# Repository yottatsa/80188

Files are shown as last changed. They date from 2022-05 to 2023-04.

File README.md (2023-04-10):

# 80188 single board modular computer

* testing and firmware development: r1
* hardware development: r2
  - [CPU card](https://github.com/yottatsa/80188/blob/main/cpu_card/cpu_card/cpu_card.pdf)
  - [ISP interface](https://github.com/yottatsa/80188/blob/main/cpu_card/isp_interface/isp_interface.pdf)

To emulate

    make run

To program and connect

    make all
    minipro -p SST39SF020A@PLCC32 --write fw/fw.bin
    minipro -p ... --write gal/....pld
    ...
    picocom -q --baud 9600 --imap lfcrlf --omap crlf [serial device]

## Configuration

* 8MHz 8086-compatible CPU
* 128KB low SRAM
* 256KB EEPROM (27C020) or Flash (SST39SF020) with in-system programming and software programming capabilities
* PC/104-compatible with 8-bit ISA bus
  - 80188 Timer A is routed to OSC
* Dual channel 16550-compatible UART
  - FTDI USB-Serial/6-pin connector on port A
  - 5V 9pin connector on port B
* AT-compatible RTC

## Notes

### r1

* minor: SYSBUS socket is too close to the CPU socket and can'tbe used with the wide connector
* minor: 16V8 /OE and GND pin names were swapped
* minor: UART1 labels are wrong
* major: 74x573 OE should be /OE
* major: 16V8 /RESET can't be used as input
* major: PLCC sockets are unreliable
* unknown: 22V10 Verification failed at address 0x16C5: File=0x01, Device=0x00
* feature: added in-system programming
* major: 39x flash doesn't work as /PGM is floating

### r0
* major: PCB socket is unreliable

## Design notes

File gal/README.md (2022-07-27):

## Board verification

- GAL is compilable and flash-able

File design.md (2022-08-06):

## References
* [Tandy 2000 BIOS](https://www.retrotronics.org/svn/t2kbios/)
* AMD 80C186/80C188 Preliminary
* Intel 80C186EA/80C188EA Microprocessor User's Manual

## Similar
* http://www.testech-elect.com/tern/acore.htm
* https://www.embeddedts.com/products/TS-2100
* https://www.jamieiles.com/80186/
* https://www.retrobrewcomputers.org/doku.php?id=boards:sbc:sbc-188:start
* https://www.kswichit.com/C188/c188sbc.htm

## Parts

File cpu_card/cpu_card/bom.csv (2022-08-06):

Item | Qty | Reference(s) | Value | LibPart | Footprint | Datasheet | Allied_Number | Description | Height | Manufacturer_Name | Manufacturer_Part_Number | Mouser Part Number | Mouser Price/Stock | RS Part Number | RS Price/Stock
1 | 1 | BT301 | RTC Battery | Device:Battery_Cell | Battery:BatteryHolder_Keystone_106_1x20mm | https://www.mouser.co.uk/datasheet/2/215/06-745914.pdf |  |  |  |  | 106 | 534-106
2 | 1 | C4 | PPWR | Device:C_Polarized_Small | Capacitor_Tantalum_SMD:CP_EIA-7343-31_Kemet-D | ~ |  |  |  |  |  | 667-EEF-CS1D100R
3 | 12 | C5, C6, C9, C10, C201, C202, C203, C204, C301, C302, C303, C304 | 100n/0.1u PWR | Device:C_Small | Capacitor_SMD:C_1206_3216Metric_Pad1.33x1.80mm_HandSolder | ~ |  |  |  |  |  | 80-C1206X104G4HACTU
4 | 2 | C101, C305 | 22p XTAL | Device:C_Small | Capacitor_SMD:C_0805_2012Metric_Pad1.18x1.45mm_HandSolder | ~ |  |  |  |  | C0805C220J1GACTU
5 | 1 | C102 | 20p XTAL | Device:C_Small | Capacitor_SMD:C_0805_2012Metric_Pad1.18x1.45mm_HandSolder | ~ |  |  |  |  | C0805C220J1GACTU
6 | 1 | C306 | 33p XTAL | Device:C_Small | Capacitor_SMD:C_0805_2012Metric_Pad1.18x1.45mm_HandSolder | ~ |  |  |  |  | C0805C220J1GACTU
8 | 1 | J1 | 80188 | MCU_Intel:80188 | 80C188:PLCC-68_SMD-Socket | http://datasheets.chipdb.org/Intel/x86/8018x/datashts/27243002.PDF |  |  |  |  | 8468-11B1-RK-TP | 517-8468-11B1-RK-TP
9 | 1 | J2 | PC/104 ISA | Connector_Generic:Conn_02x32_Odd_Even | Connector_PinSocket_2.54mm:PinSocket_2x32_P2.54mm_Vertical | ~
10 | 1 | J4 | 256K ROM | Memory_EPROM:27C020 | 69802-132LF:69802132LF | https://www.mouser.co.uk/datasheet/2/268/20005023B-709002.pdf |  |  |  |  | SST39SF020A-70-4C-NHE | 804-39SF020A7CNHE
11 | 1 | J201 | 22V10/16V8 | Logic_Programmable:PAL24 | Package_DIP:DIP-24_W7.62mm_Socket_LongPads | ~
12 | 1 | J202 | SYSBUS | Connector_Generic:Conn_02x05_Odd_Even | Connector_PinHeader_1.27mm:PinHeader_2x05_P1.27mm_Vertical | ~
13 | 1 | J302 | UART2 | Connector_Generic:Conn_02x05_Odd_Even | Connector_PinSocket_1.27mm:PinSocket_2x05_P1.27mm_Vertical | ~
14 | 1 | J303 | USB B | Connector:USB_B | A-USB_B_SMT:AUSBBSMT | http://uk.rs-online.com/web/p/products/6741331P | R1074095 |  |  |  | A-USB B/SMT |  |  | 6741331P | http://uk.rs-online.com/web/p/products/6741331P
15 | 1 | R1 | TMR1 > | Device:R_Small | Resistor_SMD:R_1206_3216Metric_Pad1.30x1.75mm_HandSolder | ~ |  | 1206 SMD 20 Kohms |  |  |  | 71-RCC120620K0FKEA
16 | 1 | R2 | ARDY | Device:R_Small | Resistor_SMD:R_1206_3216Metric_Pad1.30x1.75mm_HandSolder | ~ |  | 1206 SMD 20 Kohms |  |  |  | 71-RCC120620K0FKEA
17 | 1 | R3 | SRDY | Device:R_Small | Resistor_SMD:R_1206_3216Metric_Pad1.30x1.75mm_HandSolder | ~ |  | 1206 SMD 20 Kohms |  |  |  | 71-RCC120620K0FKEA
18 | 1 | R4 | TMR0 > | Device:R_Small | Resistor_SMD:R_1206_3216Metric_Pad1.30x1.75mm_HandSolder | ~ |  | 1206 SMD 20 Kohms |  |  |  | 71-RCC120620K0FKEA
19 | 1 | R101 | PullUp | Device:R_Small | Resistor_SMD:R_1206_3216Metric_Pad1.30x1.75mm_HandSolder | ~ |  | 1206 SMD 20 Kohms |  |  |  | 71-RCC120620K0FKEA
20 | 1 | R201 | Limit | Device:R_Small | Resistor_SMD:R_1206_3216Metric_Pad1.30x1.75mm_HandSolder | ~ |  | 1206 SMD 20 Kohms |  |  | SFR18EZPJ000 | 755-SFR18EZPJ000
21 | 1 | R302 | R4k7 | Device:R | Resistor_SMD:R_1206_3216Metric_Pad1.30x1.75mm_HandSolder | ~ |  |  |  |  | CR1206-JW-472ELF | 652-CR1206-JW-472ELF
22 | 1 | R303 | R10k | Device:R | Resistor_SMD:R_1206_3216Metric_Pad1.30x1.75mm_HandSolder | ~ |  |  |  |  | CR1206-JW-103ELF | 652-CR1206JW-103ELF
23 | 1 | R304 | PullDown | Device:R_Small | Resistor_SMD:R_1206_3216Metric_Pad1.30x1.75mm_HandSolder | ~ |  | 1206 SMD 20 Kohms |  |  |  | 71-RCC120620K0FKEA
24 | 1 | S1 | PWR | Connector:Screw_Terminal_01x02 | TerminalBlock:TerminalBlock_bornier-2_P5.08mm | ~
25 | 1 | SW201 | RESET | Switch:SW_Push | Button_Switch_SMD:SW_SPST_EVQP7A | https://www.mouser.co.uk/datasheet/2/315/sw_lt_eng_3529s_side-1289027.pdf |  |  |  |  | EVQ-P7J01P | 667-EVQP7J01P
27 | 1 | U4 | 128K SRAM | Memory_RAM:628128_DIP32_SSOP32 | Package_SO:SSOP-32_11.305x20.495mm_P1.27mm | https://www.issi.com/WW/pdf/62-65C1024AL.pdf |  | 62C1024 128KB SRAM |  | ISSI | IS62C1024AL-35QLI
28 | 2 | U201, U203 | 74LS573 | 74xx:74LS573 | Package_SO:SOIC-20W_7.5x12.8mm_P1.27mm | 74xx/74hc573.pdf |  |  |  |  | 74VHCT573AFT |  |  | 171-3540
29 | 1 | U202 | 74LS245 | 74xx:74LS245 | Package_SO:SOIC-20W_7.5x12.8mm_P1.27mm | https://www.mouser.co.uk/datasheet/2/308/1/MC74HCT245A_D-2315802.pdf |  |  |  | Texas Instruments | MC74HCT245ADWG | 863-MC74HCT245ADWG
30 | 1 | U204 | TLV809EA45DBZR | Power_Supervisor:TCM809 | Package_TO_SOT_SMD:SOT-23 | https://www.ti.com/lit/ds/symlink/tlv809e.pdf
31 | 1 | U301 | SC16C752B | SC16C752BIB48_157:SC16C752BIB48,157 | Package_QFP:TQFP-48_7x7mm_P0.5mm | http://www.nxp.com/docs/en/data-sheet/SC16C752B.pdf |  | UART Interface IC 2CH. UART 64B FIFO | 1.6 | NXP | SC16C752BIB48,157 | 771-SC16C752BIB48 | https://www.mouser.co.uk/ProductDetail/NXP-Semiconductors/SC16C752BIB48157?qs=LOCUfHb8d9sKsb5zIyQ%2FFA%3D%3D
32 | 1 | U302 | FT231XS | Interface_USB:FT231XS | Package_SO:SSOP-20_3.9x8.7mm_P0.635mm | https://www.ftdichip.com/Support/Documents/DataSheets/ICs/DS_FT231X.pdf
33 | 1 | U303 | DS12885T | DS12885T:DS12885T | Package_QFP:TQFP-32_7x7mm_P0.8mm
34 | 1 | Y1 | 16MHz | Device:Crystal_GND24_Small | Crystal:Crystal_SMD_0603-4Pin_6.0x3.5mm_HandSoldering | ~ |  | RS PRO 16MHz Crystal ±30ppm SMT 4-Pin 6 x 3.5 x 1mm
35 | 1 | Y301 | 18.432MHz | Device:Crystal_GND24_Small | Crystal:Crystal_SMD_3225-4Pin_3.2x2.5mm_HandSoldering | https://www.mouser.co.uk/datasheet/2/445/830105961709-2005258.pdf |  |  |  |  | 830105961709 | 710-830105961709
36 | 1 | Y302 | 32.768kHz | Device:Crystal_Small | Crystal:Crystal_SMD_EuroQuartz_EQ161-2Pin_3.2x1.5mm_HandSoldering | https://www.mouser.co.uk/datasheet/2/122/ECX_34R-845158.pdf |  |  |  |  | ECS-.327-6-34R-TR | 520-.327-6-34RT

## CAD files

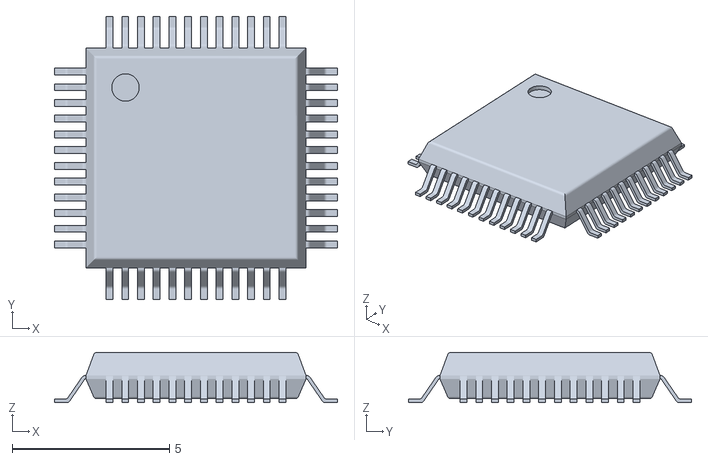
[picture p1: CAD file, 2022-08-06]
cpu_card/SC16C752BIB48_157/SC16C752BIB48,157.stl
9.00 x 9.00 x 1.60

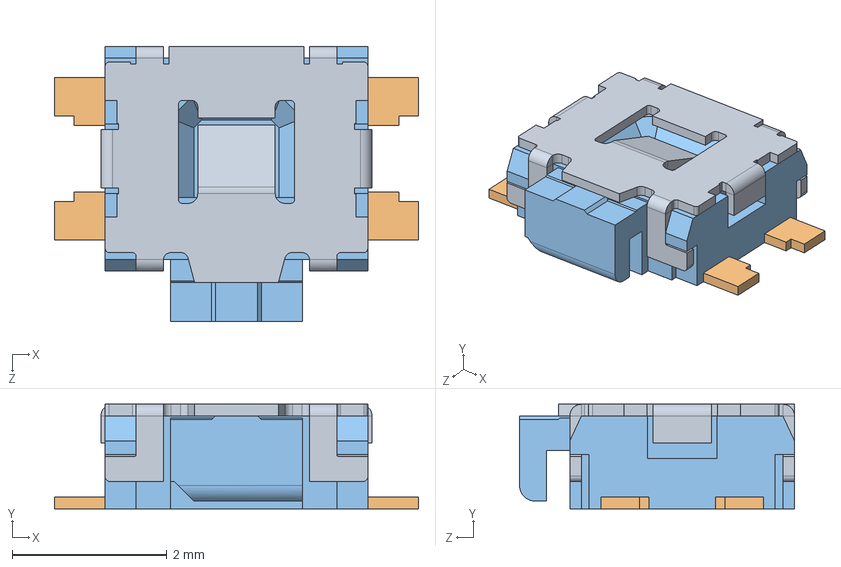
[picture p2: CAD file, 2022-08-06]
cpu_card/SW_SPST_EVQP7A/EVQ-P7A01P--3DModel-STEP-269445.STEP
4.70 x 1.35 x 3.55 mm

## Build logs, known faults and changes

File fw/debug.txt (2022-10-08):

_mon:
_warmreset:
_putch:
_puts:
_getch:
_putnibble:
.hex:
.print:
_putbyte:
_putdec:
.reduceprint:
.print:
.leadzero:
_setup:
		say_what 0xb007		; jumped to the setup code
		say_what 0xb105
_soc_failure:
		say_what 0xdead
_soc_passed:
		say_what 0xc0de
_set_mem:
_set_pcs:
_test_setup_rom:
.loop:
.check:
.rom_failure:
		say_what 0x0bad
.end:
		say_what bx		; checksum
		say_what 0x1337		; rom check passed
_set_sp:
		say_what ss		; 0x1000
		say_what sp		; 0xffff
_test_ram_words:
		say_what si		; ram test address
		say_what cx		; ram test value to write
		say_what bx		; ram test value readback
.ram_failure:
.halt:
		say_what 0x2bad
.end:
		say_what 0xcafe		; memory test passed
_init_serial:
_check_rtc:
.datetime:
.bad_rtc:
.reset_rtc:
.end:
_finish:
_restart:

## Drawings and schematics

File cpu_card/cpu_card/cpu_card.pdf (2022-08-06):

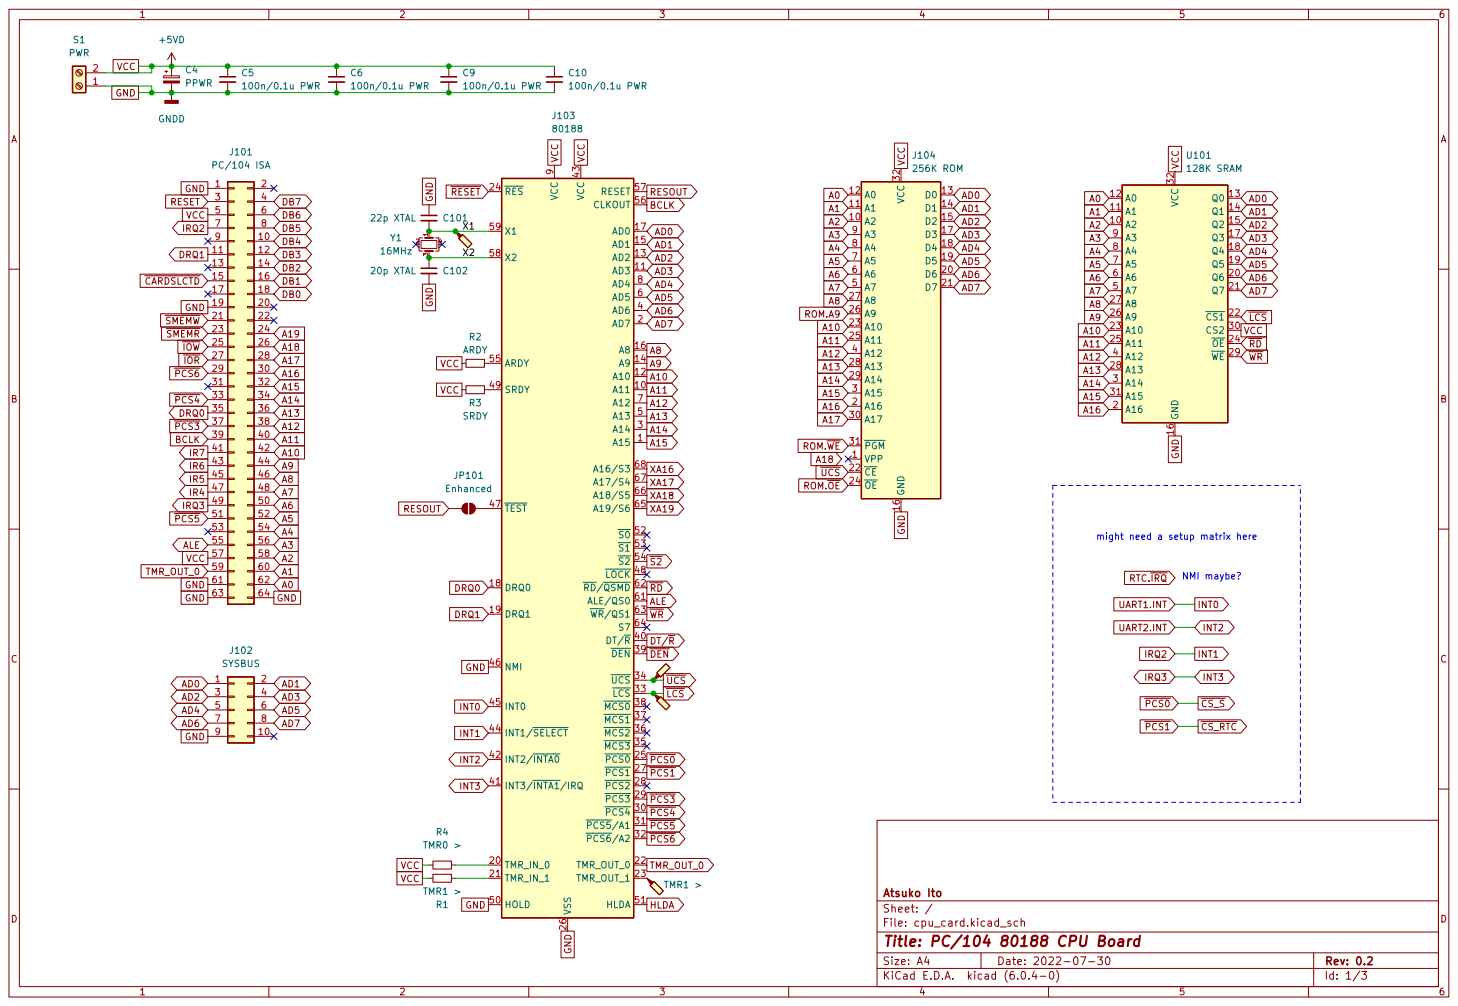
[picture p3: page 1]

might need a setup matrix here

File: cpu_card.kicad_sch Sheet: / Atsuko Ito

Id: 1/3 Title: PC/104 80188 CPU Board

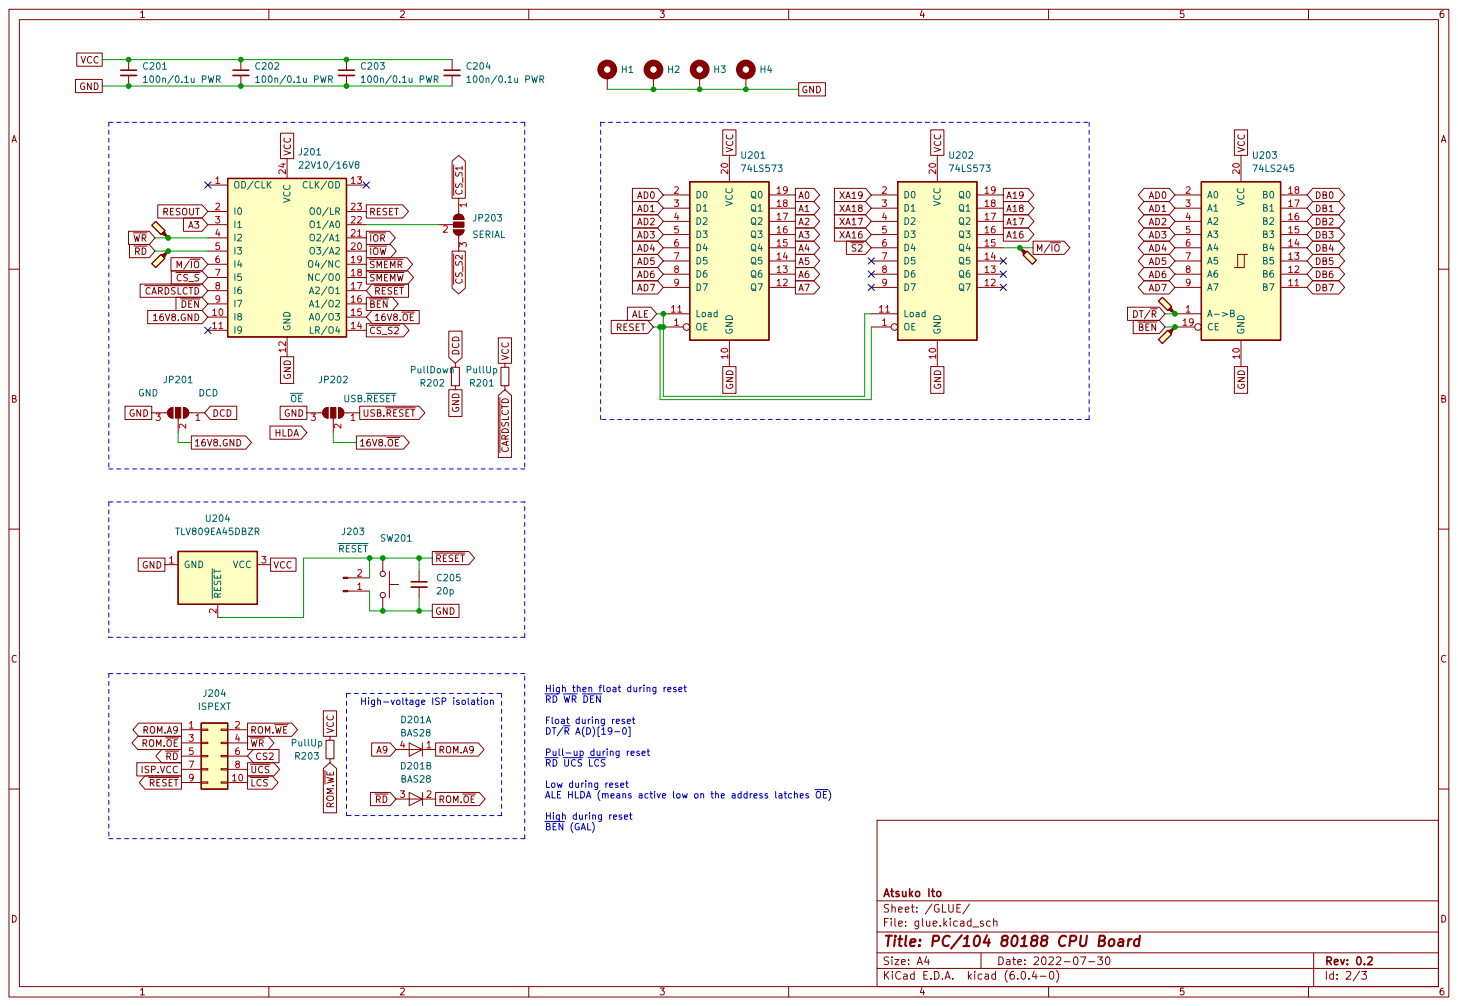
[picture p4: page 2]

High-voltage ISP isolation

High then float during reset
~{RD} ~{WR} ~{DEN}

Pull-up during reset
~{RD} ~{UCS} ~{LCS}

Low during reset
ALE HLDA (means active low on the address latches ~{OE})

File: glue.kicad_sch Sheet: /GLUE/ Atsuko Ito

Id: 2/3 Title: PC/104 80188 CPU Board

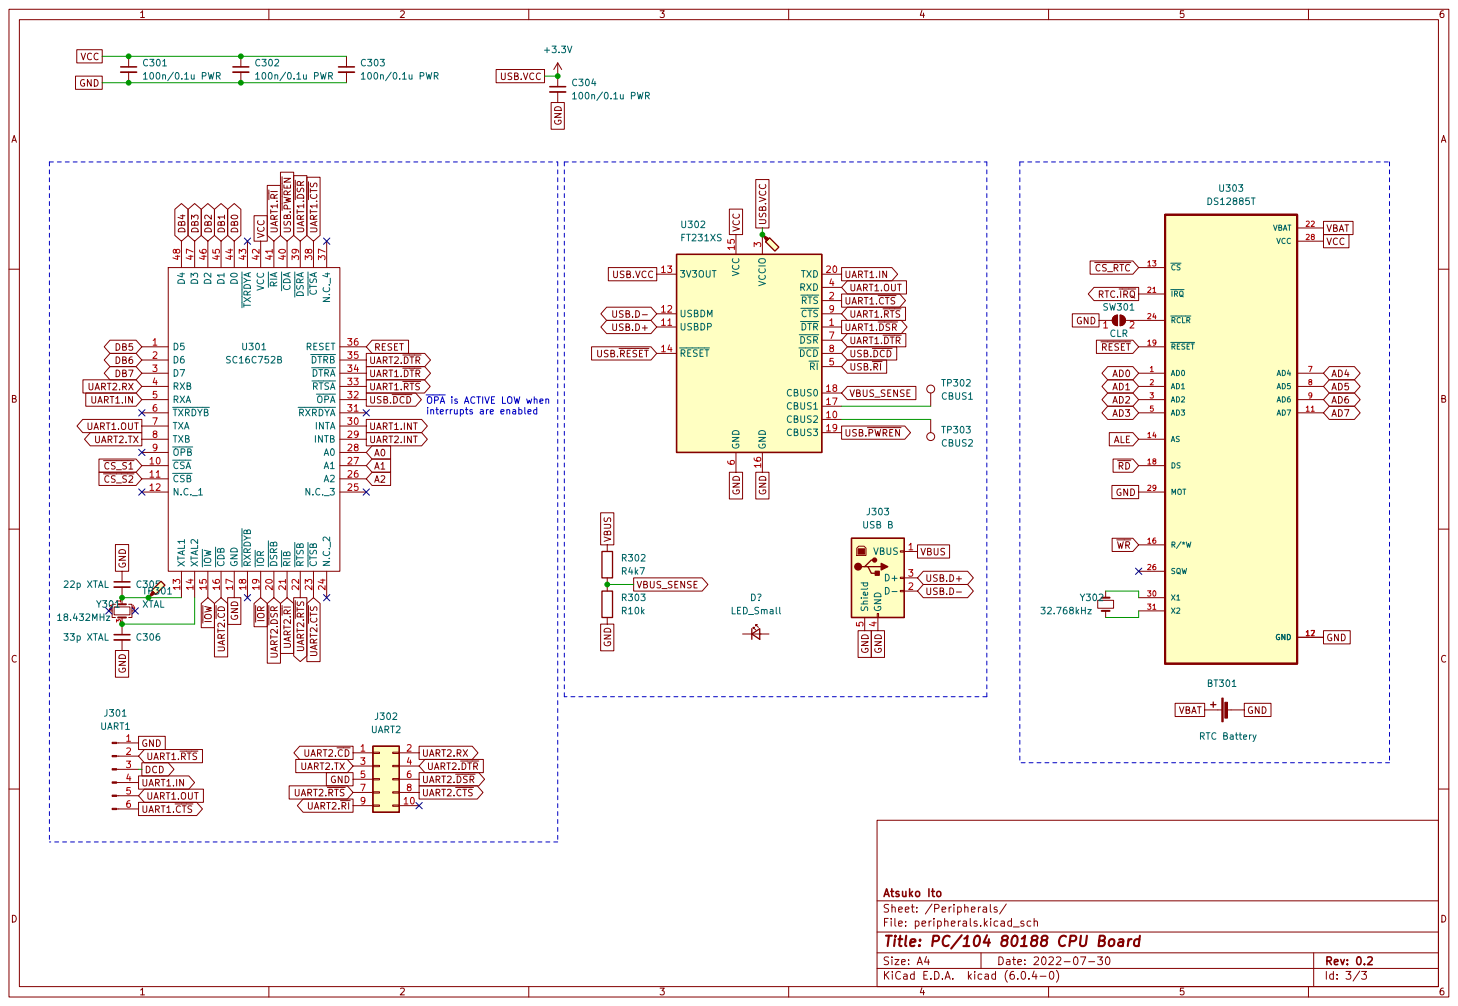
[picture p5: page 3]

~{OPA} is ACTIVE LOW when
interrupts are enabled

32.768kHz UART2.~{RI} UART1.OUT UART1.~{CTS} UART1.IN

Sheet: /Peripherals/ Atsuko Ito

File: peripherals.kicad_sch
Id: 3/3 Title: PC/104 80188 CPU Board

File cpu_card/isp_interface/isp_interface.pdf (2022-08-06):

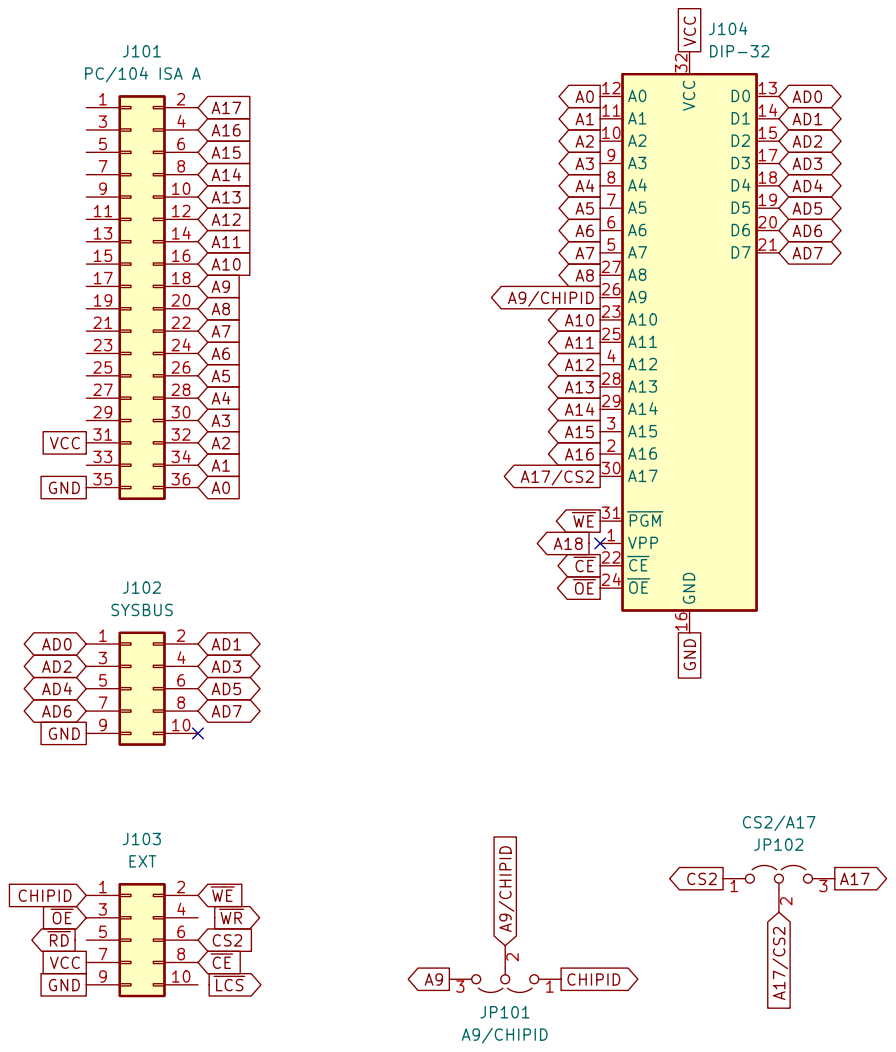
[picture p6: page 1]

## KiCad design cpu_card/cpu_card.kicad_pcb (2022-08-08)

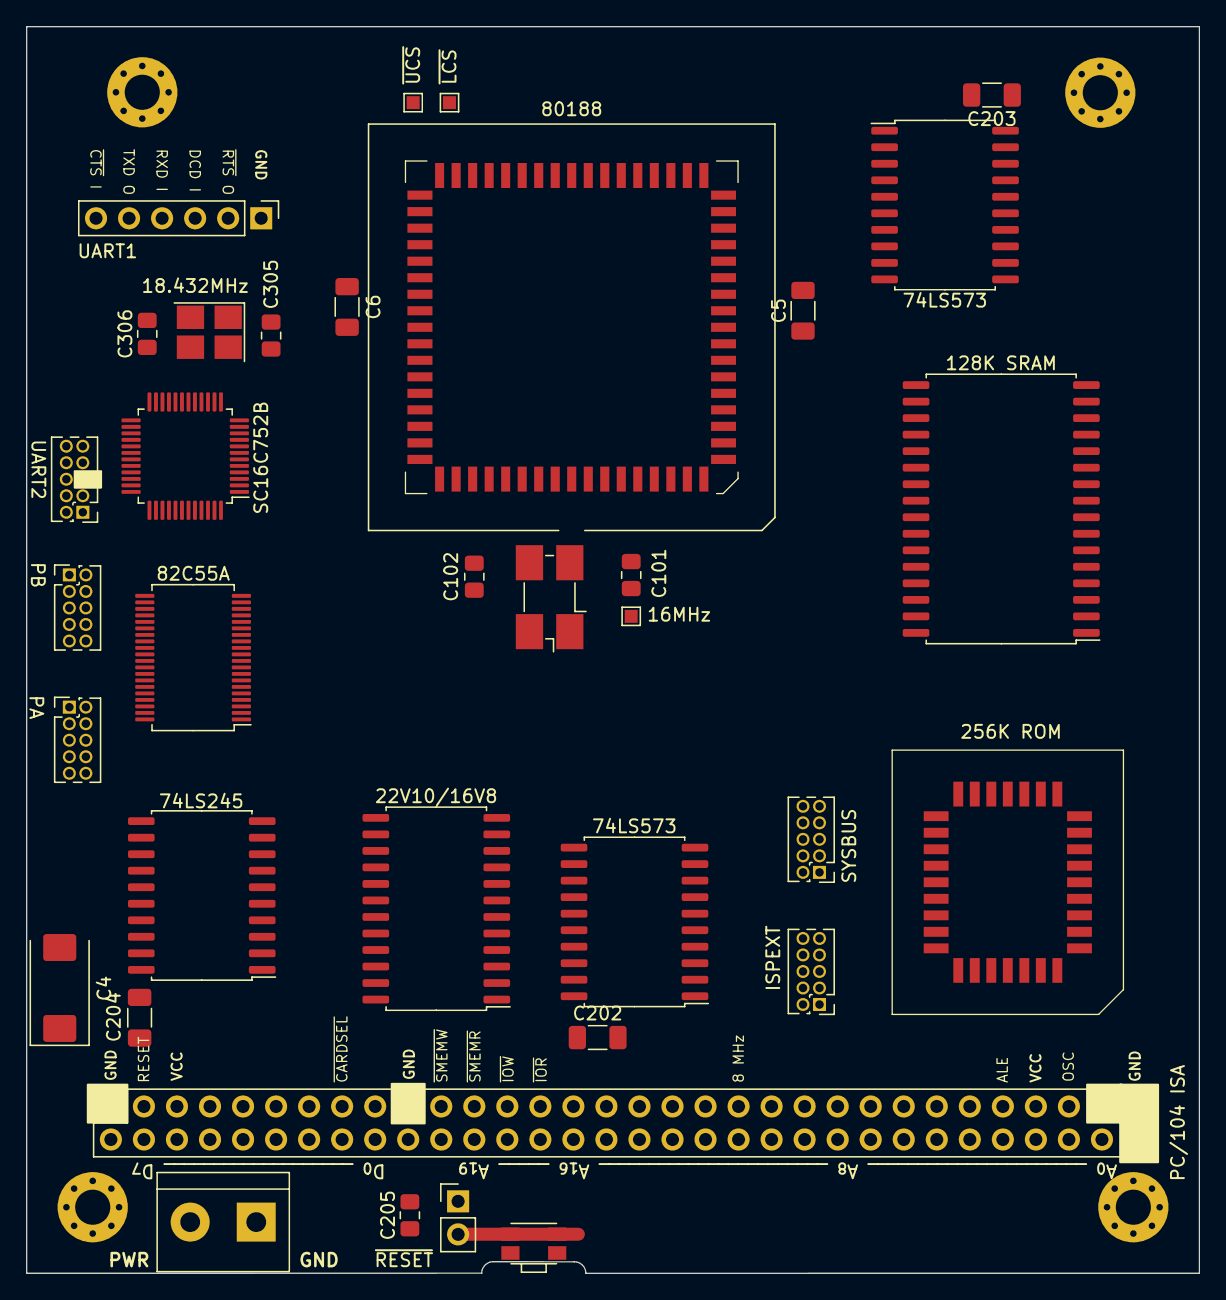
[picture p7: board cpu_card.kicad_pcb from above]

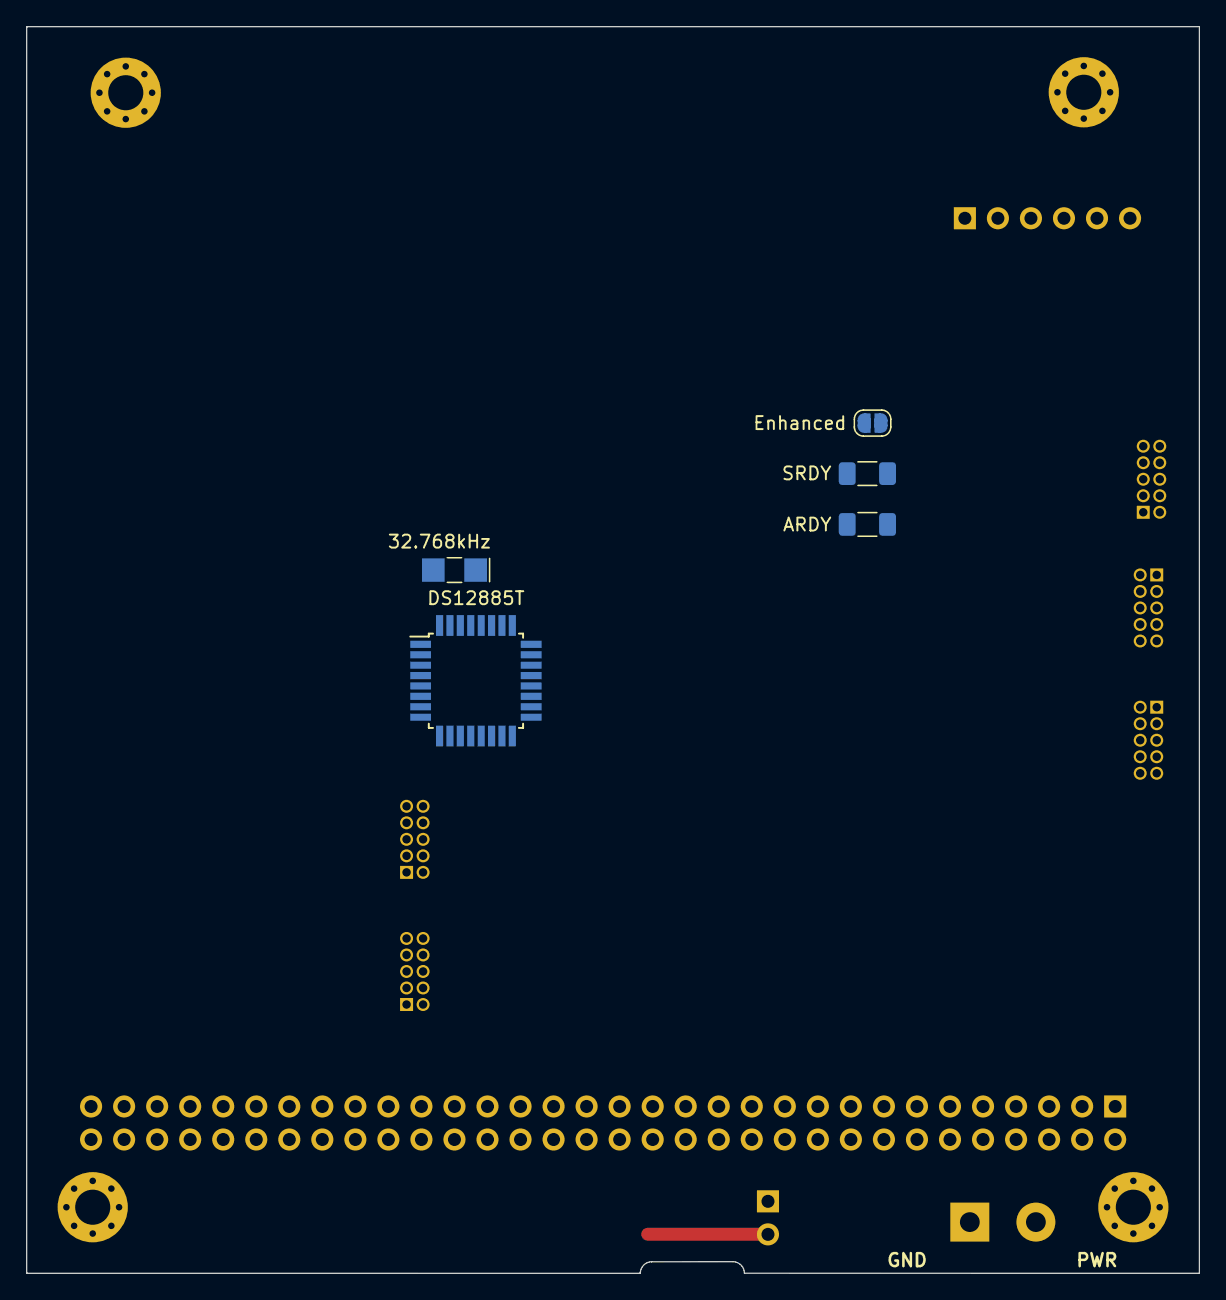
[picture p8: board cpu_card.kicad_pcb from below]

Board: 4 copper layers, 90.2 x 95.9 mm, 44 parts (5 on the bottom side), 116 nets.

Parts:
C4: PPWR; CP_EIA-7343-31_Kemet-D
C5, C6, C202, C203, C204: 100n/0.1u PWR; C_1206_3216Metric_Pad1.33x1.80mm_HandSolder
C101, C305: 22p XTAL; C_0805_2012Metric_Pad1.18x1.45mm_HandSolder
C102: 20p XTAL; C_0805_2012Metric_Pad1.18x1.45mm_HandSolder
C205: 20p; C_0805_2012Metric_Pad1.18x1.45mm_HandSolder
C306: 33p XTAL; C_0805_2012Metric_Pad1.18x1.45mm_HandSolder
H1, H2, H3, H4: MountingHole_2.7mm_M2.5_Pad_Via
J101: PC/104 ISA; PinSocket_2x32_P2.54mm_Vertical
J102: SYSBUS; PinHeader_2x05_P1.27mm_Vertical
J103: 80188; PLCC-68_SMD-Socket
J104: 256K ROM; 69802132LF
J201: 22V10/16V8; SOIC-24W_7.5x15.4mm_P1.27mm
J203: ~{RESET}; PinHeader_1x02_P2.54mm_Vertical
J204: ISPEXT; PinHeader_2x05_P1.27mm_Vertical
J301: UART1; PinHeader_1x06_P2.54mm_Vertical
J302: UART2; PinHeader_2x05_P1.27mm_Vertical
J304: PB; PinHeader_2x05_P1.27mm_Vertical
J305: PA; PinHeader_2x05_P1.27mm_Vertical
JP101: Enhanced; SolderJumper-2_P1.3mm_Open_RoundedPad1.0x1.5mm
R2: ARDY; R_1206_3216Metric_Pad1.30x1.75mm_HandSolder
R3: SRDY; R_1206_3216Metric_Pad1.30x1.75mm_HandSolder
S1: PWR; TerminalBlock_bornier-2_P5.08mm
SW201: RESET; SW_SPST_EVQP7A
TP101: XTAL; TestPoint_Pad_1.0x1.0mm
TP103: ~{UCS}; TestPoint_Pad_1.0x1.0mm
TP104: ~{LCS}; TestPoint_Pad_1.0x1.0mm
U101: 128K SRAM; SSOP-32_11.305x20.495mm_P1.27mm
U201, U202: 74LS573; SOIC-20W_7.5x12.8mm_P1.27mm
U203: 74LS245; SOIC-20W_7.5x12.8mm_P1.27mm
U301: SC16C752B; TQFP-48_7x7mm_P0.5mm
U303: DS12885T; TQFP-32_7x7mm_P0.8mm
U304: 82C55A; TSSOP-40_6.1x11mm_P0.5mm
Y1: 16MHz; Crystal_SMD_0603-4Pin_6.0x3.5mm_HandSoldering
Y301: 18.432MHz; Crystal_SMD_3225-4Pin_3.2x2.5mm_HandSoldering
Y302: 32.768kHz; Crystal_SMD_EuroQuartz_EQ161-2Pin_3.2x1.5mm_HandSoldering

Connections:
/X1: C101.2, J103.59 (X1), TP101.1, Y1.1
/X2: C102.1, J103.58 (X2), Y1.3
A0: J101.62, J104.12 (A0), U101.12 (A0), U201.19 (Q0), U301.28 (A0), U304.9 (A0)
A1: J101.60, J104.11 (A1), U101.11 (A1), U201.18 (Q1), U301.27 (A1), U304.8 (A1)
A2: J101.58, J104.10 (A2), U101.10 (A2), U201.17 (Q2), U301.26 (A2)
A3: J101.56, J104.9 (A3), J201.3 (I1), U101.9 (A3), U201.16 (Q3)
A4: J101.54, J104.8 (A4), U101.8 (A4), U201.15 (Q4)
A5: J101.52, J104.7 (A5), U101.7 (A5), U201.14 (Q5)
A6: J101.50, J104.6 (A6), U101.6 (A6), U201.13 (Q6)
A7: J101.48, J104.5 (A7), U101.5 (A7), U201.12 (Q7)
A8: J101.46, J103.16 (A8), J104.27 (A8), U101.27 (A8)
A9: J101.44, J103.14 (A9), U101.26 (A9)
A10: J101.42, J103.12 (A10), J104.23 (A10), U101.23 (A10)
A11: J101.40, J103.10 (A11), J104.25 (A11), U101.25 (A11)
A12: J101.38, J103.7 (A12), J104.4 (A12), U101.4 (A12)
A13: J101.36, J103.5 (A13), J104.28 (A13), U101.28 (A13)
A14: J101.34, J103.3 (A14), J104.29 (A14), U101.3 (A14)
A15: J101.32, J103.1 (A15), J104.3 (A15), U101.31 (A15)
A16: J101.30, J104.2 (A16), U101.2 (A16), U202.16 (Q3)
A17: J101.28, J104.30 (A17), U202.17 (Q2)
A18: J101.26, U202.18 (Q1)
A19: J101.24, U202.19 (Q0)
AD0: J102.1, J103.17 (AD0), J104.13 (D0), U101.13 (Q0), U201.2 (D0), U203.2 (A0), U303.1 (AD0)
AD1: J102.2, J103.15 (AD1), J104.14 (D1), U101.14 (Q1), U201.3 (D1), U203.3 (A1), U303.2 (AD1)
AD2: J102.3, J103.13 (AD2), J104.15 (D2), U101.15 (Q2), U201.4 (D2), U203.4 (A2), U303.3 (AD2)
AD3: J102.4, J103.11 (AD3), J104.17 (D3), U101.17 (Q3), U201.5 (D3), U203.5 (A3), U303.5 (AD3)
AD4: J102.5, J103.8 (AD4), J104.18 (D4), U101.18 (Q4), U201.6 (D4), U203.6 (A4), U303.7 (AD4)
AD5: J102.6, J103.6 (AD5), J104.19 (D5), U101.19 (Q5), U201.7 (D5), U203.7 (A5), U303.8 (AD5)
AD6: J102.7, J103.4 (AD6), J104.20 (D6), U101.20 (Q6), U201.8 (D6), U203.8 (A6), U303.9 (AD6)
AD7: J102.8, J103.2 (AD7), J104.21 (D7), U101.21 (Q7), U201.9 (D7), U203.9 (A7), U303.11 (AD7)
ALE: J101.3, J101.55, J103.61 (ALE/QS0), J201.23 (O0/LR), U201.1 (OE), U201.11 (Load), U202.1 (OE), U202.11 (Load), U301.36 (RESET), U303.14 (AS), U304.35 (RESET)
BCLK: J101.39, J103.56 (CLKOUT)
DB0: J101.18, U203.18 (B0), U301.44 (D0), U304.34 (D0)
DB1: J101.16, U203.17 (B1), U301.45 (D1), U304.33 (D1)
DB2: J101.14, U203.16 (B2), U301.46 (D2), U304.32 (D2)
DB3: J101.12, U203.15 (B3), U301.47 (D3), U304.31 (D3)
DB4: J101.10, U203.14 (B4), U301.48 (D4), U304.30 (D4)
DB5: J101.8, U203.13 (B5), U301.1 (D5), U304.29 (D5)
DB6: J101.6, U203.12 (B6), U301.2 (D6), U304.28 (D6)
DB7: J101.4, U203.11 (B7), U301.3 (D7), U304.27 (D7)
DCD: J201.10 (I8), J301.3
DRQ0: J101.35, J103.18 (DRQ0)
DRQ1: J101.11, J103.19 (DRQ1)
DT/~R: J103.40 (DT/~R), U203.1 (A->B)
GND: C4.2, C5.2, C6.2, C101.1, C102.2, C202.2, C203.2, C204.2, C205.2, C305.1, C306.2, H1.1, H2.1, H3.1, H4.1, J101.1, J101.19, J101.61, J101.63, J101.64, J102.9, J103.26 (VSS), J103.50 (HOLD), J103.60 (VSS), J104.16 (GND), J201.12 (GND), J203.1, J301.1, J302.5, J304.9, J305.9, S1.1, SW201.2, U101.16 (GND), U201.10 (GND), U202.10 (GND), U203.10 (GND), U301.17 (GND), U303.12 (GND), U303.17 (GND), U303.29 (MOT), U304.7 (GND)
INT0: J103.45 (INT0), U301.30 (INTA)
INT1: J101.7, J103.44 (INT1/~SELECT)
INT2: J103.42 (INT2/~INTA0), U301.29 (INTB)
INT3: J101.49, J103.41 (INT3/~INTA1/IRQ)
M/~IO: J201.6 (I4), U202.15 (Q4)
unnamed: C305.2, U301.13 (XTAL1), Y301.1
unnamed: C306.1, U301.14 (XTAL2), Y301.3
unnamed: J103.47 (~TEST), JP101.2 (B)
unnamed: J103.49 (SRDY), R3.2
unnamed: J103.55 (ARDY), R2.2
unnamed: J304.1, U304.18 (PB0)
unnamed: J304.2, U304.19 (PB1)
unnamed: J304.3, U304.20 (PB2)
unnamed: J304.4, U304.21 (PB3)
unnamed: J304.5, U304.22 (PB4)
unnamed: J304.6, U304.23 (PB5)
unnamed: J304.7, U304.24 (PB6)
unnamed: J304.8, U304.25 (PB7)
unnamed: J305.1, U304.4 (PA0)
unnamed: J305.2, U304.3 (PA1)
unnamed: J305.3, U304.2 (PA2)
unnamed: J305.4, U304.1 (PA3)
unnamed: J305.5, U304.40 (PA4)
unnamed: J305.6, U304.39 (PA5)
unnamed: J305.7, U304.38 (PA6)
unnamed: J305.8, U304.37 (PA7)
unnamed: U303.30 (X1), Y302.1
unnamed: U303.31 (X2), Y302.2
RESOUT: J103.57 (RESET), J201.2 (I0), JP101.1 (A)
ROM.A9: J104.26 (A9), J204.1
ROM.~OE: J104.24 (~OE), J204.3
ROM.~WE: J104.31 (~PGM), J204.2
TMR_OUT_0: J101.59, J103.22 (TMR_OUT_0)
UART1.IN: J301.4, U301.5 (RXA)
UART1.OUT: J301.5, U301.7 (TXA)
UART1.~CTS: J301.6, U301.38 (~CTSA)
UART1.~RTS: J301.2, U301.33 (~RTSA)
UART2.RX: J302.2, U301.4 (RXB)
UART2.TX: J302.3, U301.8 (TXB)
UART2.~CD: J302.1, U301.16 (~CDB)
UART2.~CTS: J302.8, U301.23 (~CTSB)
UART2.~DSR: J302.6, U301.20 (~DSRB)
UART2.~DTR: J302.4, U301.35 (~DTRB)
UART2.~RI: J302.9, U301.21 (~RIB)
UART2.~RTS: J302.7, U301.22 (~RTSB)
VCC: C4.1, C5.1, C6.1, C202.1, C203.1, C204.1, J101.5, J101.57, J103.9 (VCC), J103.43 (VCC), J104.32 (VCC), J201.24 (VCC), R2.1, R3.1, S1.2, U101.30 (CS2), U101.32 (VCC), U201.20 (VCC), U202.20 (VCC), U203.20 (VCC), U301.42 (VCC), U303.28 (VCC), U304.26 (VCC)
XA16: J103.68 (A16/S3), U202.5 (D3)
XA17: J103.67 (A17/S4), U202.4 (D2)
XA18: J103.66 (A18/S5), U202.3 (D1)
XA19: J103.65 (A19/S6), U202.2 (D0)
~BEN: J201.16 (A1/O2), U203.19 (CE)
~CARDSLCTD: J101.15, J201.8 (I6)
~CS_RTC: J103.27 (~PCS1), U303.13 (~CS)
~CS_S1: J201.22 (O1/A0), U301.10 (~CSA)
~CS_S2: J201.14 (LR/O4), U301.11 (~CSB)
~CS_S: J103.25 (~PCS0), J201.7 (I5)
~DEN: J103.39 (~DEN), J201.9 (I7)
~IOR: J101.27, J201.21 (O2/A1), U301.19 (~IOR), U304.5 (~RD)
~IOW: J101.25, J201.20 (O3/A2), U301.15 (~IOW), U304.36 (~WR)
~LCS: J103.33 (~LCS), J204.10, TP104.1, U101.22 (~CS1)
~PCS3: J101.37, J103.29 (~PCS3)
~PCS4: J101.33, J103.30 (~PCS4)
~PCS5: J101.51, J103.31 (~PCS5/A1)
~PCS6: J101.29, J103.32 (~PCS6/A2)
~RD: J103.62 (~RD/~QSMD), J201.5 (I3), J204.5, U101.24 (~OE), U303.18 (DS)
~RESET: C205.1, J103.24 (~RES), J201.17 (A2/O1), J203.2, J204.9, SW201.1, U303.19 (~RESET)
~S2: J103.54 (~S2), U202.6 (D4)
~SMEMR: J101.23, J201.19 (O4/NC)
~SMEMW: J101.21, J201.18 (NC/O0)
~UCS: J103.34 (~UCS), J104.22 (~CE), J204.8, TP103.1
~WR: J103.63 (~WR/QS1), J201.4 (I2), J204.4, U101.29 (~WE), U303.16 (R/*W)

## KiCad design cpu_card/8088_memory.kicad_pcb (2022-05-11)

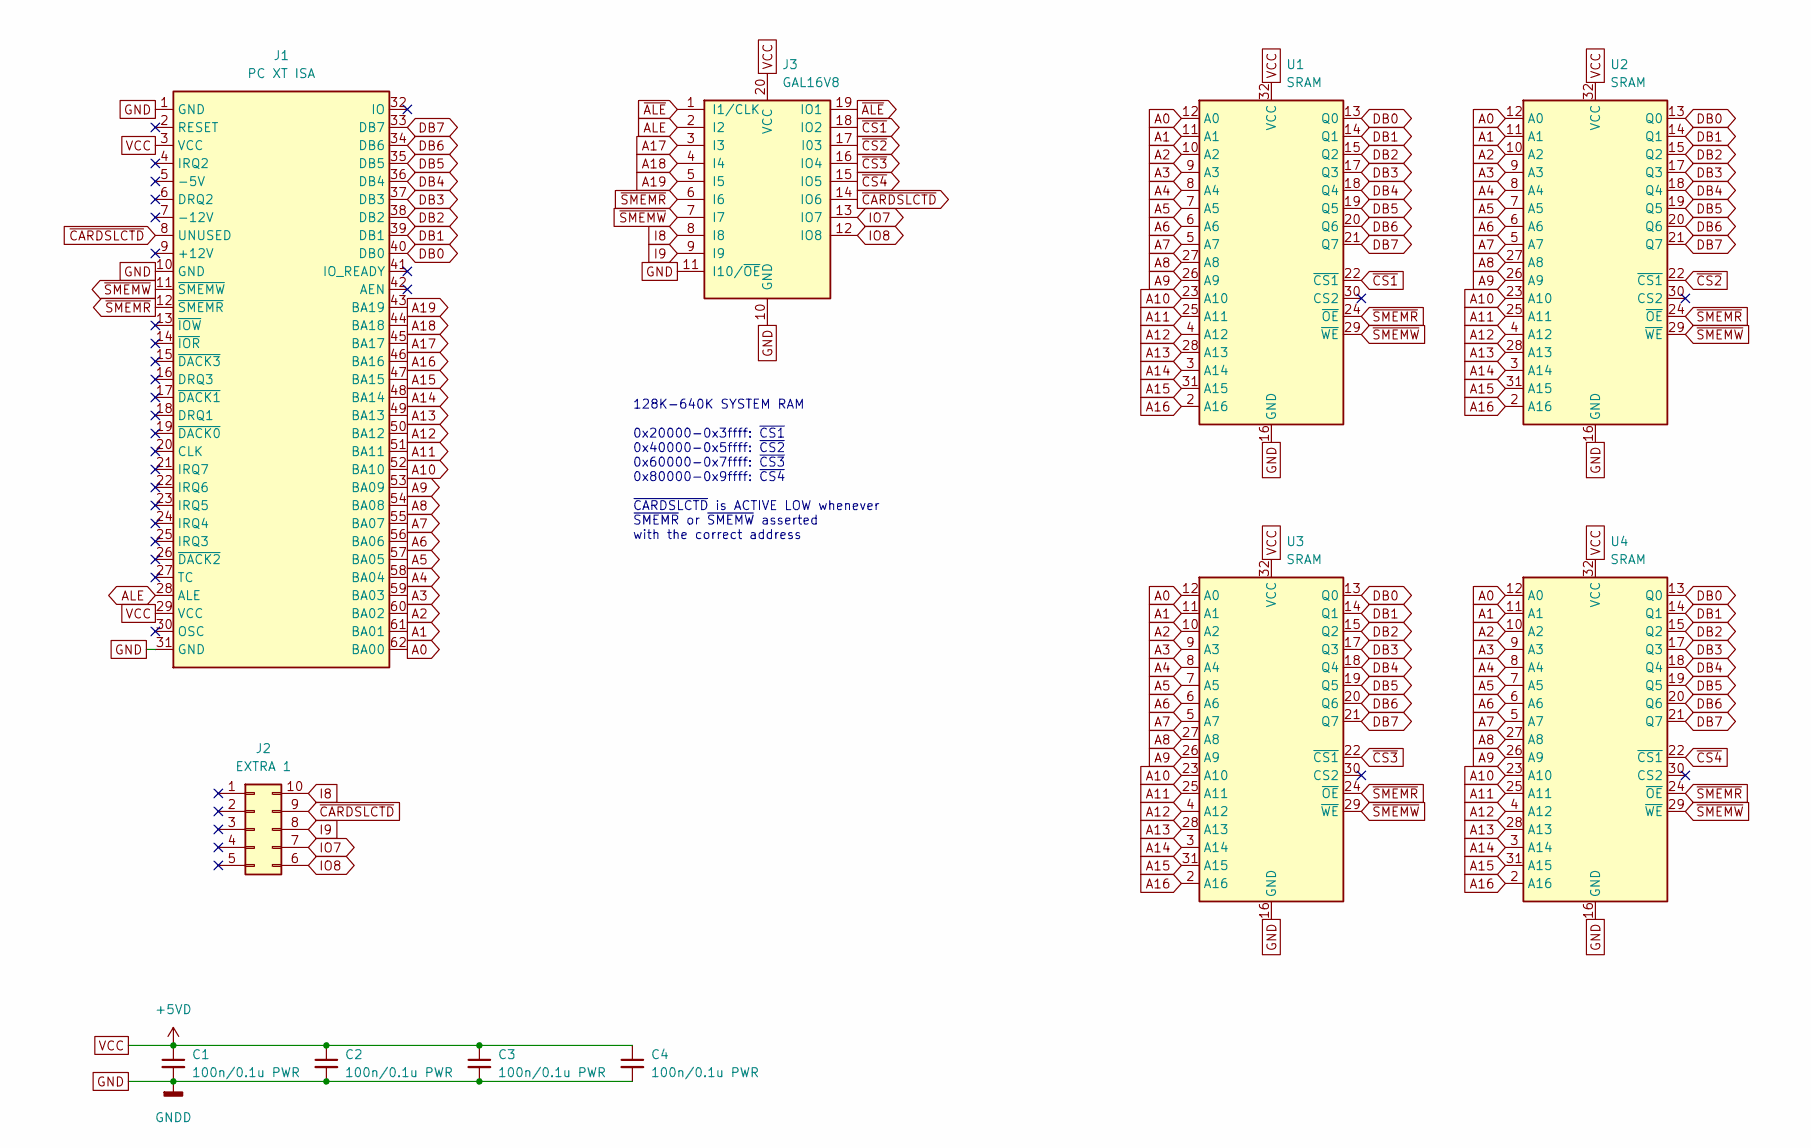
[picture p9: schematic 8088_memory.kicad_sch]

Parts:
C1, C2, C3, C4: 100n/0.1u PWR; C_1206_3216Metric_Pad1.33x1.80mm_HandSolder; Mouser Part Number 80-C1206X104G4HACTU
J1: PC XT ISA; ISA-X
J2: EXTRA 1; IDC-Header_2x05_P2.54mm_Vertical
J3: GAL16V8; DIP-20_W7.62mm_Socket; Manufacturer_Part_Number ATF16V8CZ-15PU; Mouser Part Number 556-AF16V8CZ15PU
U1, U2, U3, U4: SRAM; SSOP-32_11.305x20.495mm_P1.27mm; Manufacturer_Part_Number IS62C1024AL-35QLI

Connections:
A0: J1.62 (BA00), U1.12 (A0), U2.12 (A0), U3.12 (A0), U4.12 (A0)
A1: J1.61 (BA01), U1.11 (A1), U2.11 (A1), U3.11 (A1), U4.11 (A1)
A2: J1.60 (BA02), U1.10 (A2), U2.10 (A2), U3.10 (A2), U4.10 (A2)
A3: J1.59 (BA03), U1.9 (A3), U2.9 (A3), U3.9 (A3), U4.9 (A3)
A4: J1.58 (BA04), U1.8 (A4), U2.8 (A4), U3.8 (A4), U4.8 (A4)
A5: J1.57 (BA05), U1.7 (A5), U2.7 (A5), U3.7 (A5), U4.7 (A5)
A6: J1.56 (BA06), U1.6 (A6), U2.6 (A6), U3.6 (A6), U4.6 (A6)
A7: J1.55 (BA07), U1.5 (A7), U2.5 (A7), U3.5 (A7), U4.5 (A7)
A8: J1.54 (BA08), U1.27 (A8), U2.27 (A8), U3.27 (A8), U4.27 (A8)
A9: J1.53 (BA09), U1.26 (A9), U2.26 (A9), U3.26 (A9), U4.26 (A9)
A10: J1.52 (BA10), U1.23 (A10), U2.23 (A10), U3.23 (A10), U4.23 (A10)
A11: J1.51 (BA11), U1.25 (A11), U2.25 (A11), U3.25 (A11), U4.25 (A11)
A12: J1.50 (BA12), U1.4 (A12), U2.4 (A12), U3.4 (A12), U4.4 (A12)
A13: J1.49 (BA13), U1.28 (A13), U2.28 (A13), U3.28 (A13), U4.28 (A13)
A14: J1.48 (BA14), U1.3 (A14), U2.3 (A14), U3.3 (A14), U4.3 (A14)
A15: J1.47 (BA15), U1.31 (A15), U2.31 (A15), U3.31 (A15), U4.31 (A15)
A16: J1.46 (BA16), U1.2 (A16), U2.2 (A16), U3.2 (A16), U4.2 (A16)
A17: J1.45 (BA17), J3.3 (I3)
A18: J1.44 (BA18), J3.4 (I4)
A19: J1.43 (BA19), J3.5 (I5)
ALE: J1.28 (ALE), J3.2 (I2)
DB0: J1.40 (DB0), U1.13 (Q0), U2.13 (Q0), U3.13 (Q0), U4.13 (Q0)
DB1: J1.39 (DB1), U1.14 (Q1), U2.14 (Q1), U3.14 (Q1), U4.14 (Q1)
DB2: J1.38 (DB2), U1.15 (Q2), U2.15 (Q2), U3.15 (Q2), U4.15 (Q2)
DB3: J1.37 (DB3), U1.17 (Q3), U2.17 (Q3), U3.17 (Q3), U4.17 (Q3)
DB4: J1.36 (DB4), U1.18 (Q4), U2.18 (Q4), U3.18 (Q4), U4.18 (Q4)
DB5: J1.35 (DB5), U1.19 (Q5), U2.19 (Q5), U3.19 (Q5), U4.19 (Q5)
DB6: J1.34 (DB6), U1.20 (Q6), U2.20 (Q6), U3.20 (Q6), U4.20 (Q6)
DB7: J1.33 (DB7), U1.21 (Q7), U2.21 (Q7), U3.21 (Q7), U4.21 (Q7)
GND: C1.2, C2.2, C3.2, C4.2, J1.1 (GND), J1.10 (GND), J1.31 (GND), J3.10 (GND), J3.11 (I10/~OE), U1.16 (GND), U2.16 (GND), U3.16 (GND), U4.16 (GND)
I8: J2.10, J3.8 (I8)
I9: J2.8, J3.9 (I9)
IO7: J2.7, J3.13 (IO7)
IO8: J2.6, J3.12 (IO8)
VCC: C1.1, C2.1, C3.1, C4.1, J1.3 (VCC), J1.29 (VCC), J3.20 (VCC), U1.32 (VCC), U2.32 (VCC), U3.32 (VCC), U4.32 (VCC)
~ALE: J3.1 (I1/CLK), J3.19 (IO1)
~CS1: J3.18 (IO2), U1.22 (~CS1)
~CS2: J3.17 (I03), U2.22 (~CS1)
~CS3: J3.16 (IO4), U3.22 (~CS1)
~CS4: J3.15 (IO5), U4.22 (~CS1)
~PACK: J1.8 (UNUSED), J2.9, J3.14 (IO6)
~SMEMR: J1.12 (~SMEMR), J3.6 (I6), U1.24 (~OE), U2.24 (~OE), U3.24 (~OE), U4.24 (~OE)
~SMEMW: J1.11 (~SMEMW), J3.7 (I7), U1.29 (~WE), U2.29 (~WE), U3.29 (~WE), U4.29 (~WE)

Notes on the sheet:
128K-640K SYSTEM RAM 0x20000-0x3ffff: ~{CS1} 0x40000-0x5ffff: ~{CS2} 0x60000-0x7ffff: ~{CS3} 0x80000-0x9ffff: ~{CS4} ~{CARDSLCTD} is ACTIVE LOW whenever ~{SMEMR} or ~{SMEMW} asserted with the correct address

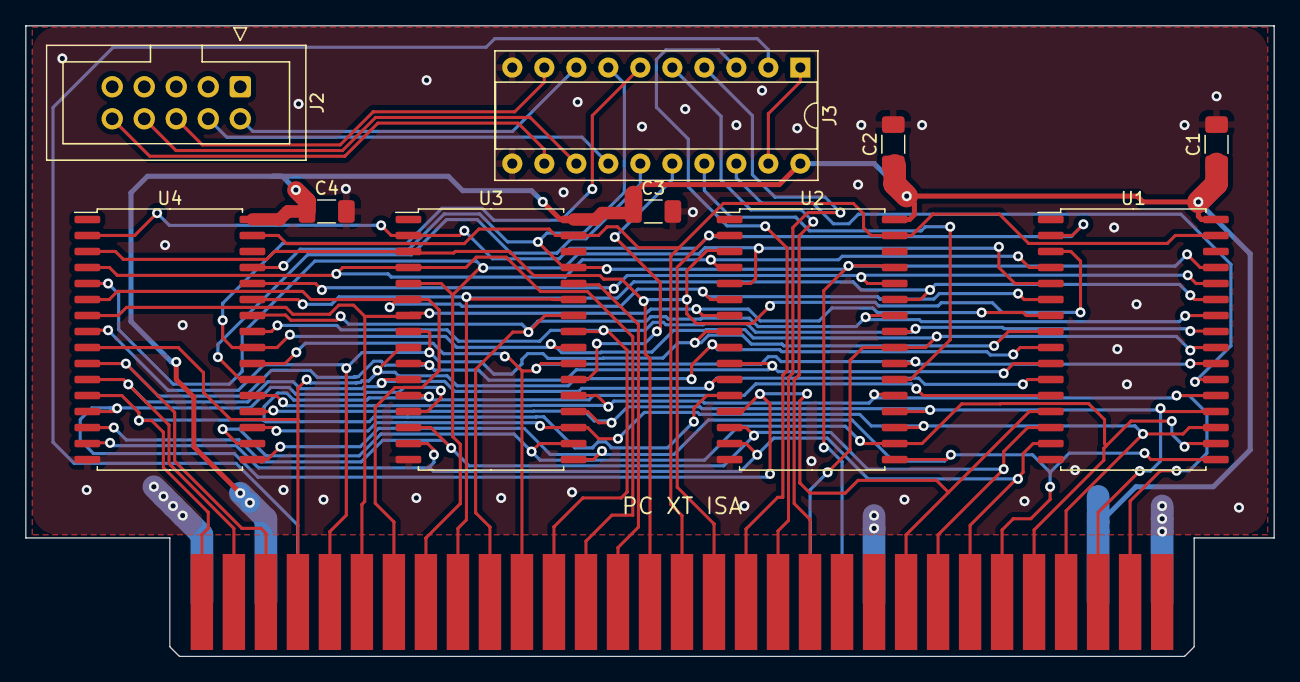
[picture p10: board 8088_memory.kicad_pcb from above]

Board: 2 copper layers, 99.1 x 50.0 mm, 11 parts (0 on the bottom side), 43 nets.

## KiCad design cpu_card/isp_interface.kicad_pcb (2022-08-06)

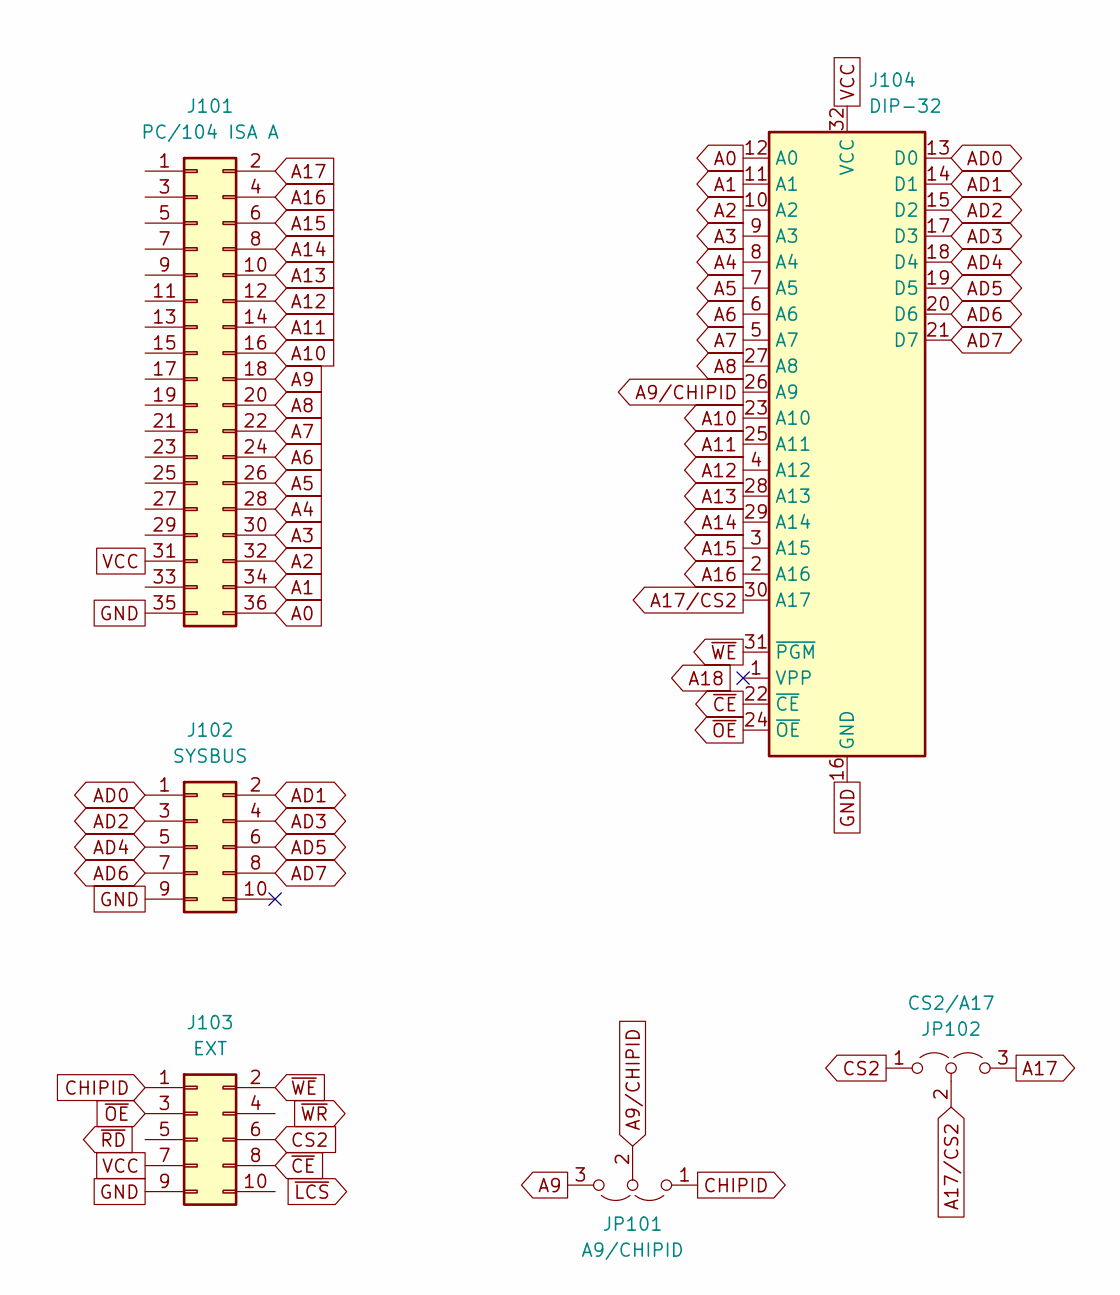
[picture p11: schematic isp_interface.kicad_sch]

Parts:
J101: PC/104 ISA A; PinSocket_2x18_P2.54mm_Vertical
J102: SYSBUS; PinHeader_2x05_P1.27mm_Vertical
J103: EXT; PinHeader_2x05_P1.27mm_Vertical
J104: DIP-32; DIP-32_W15.24mm_LongPads; Manufacturer_Part_Number SST39SF020A-70-4C-NHE; Mouser Part Number 804-39SF020A7CNHE
JP101: A9/CHIPID; PinHeader_1x03_P2.54mm_Vertical
JP102: CS2/A17; PinHeader_1x03_P2.54mm_Vertical

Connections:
A0: J101.36, J104.12 (A0)
A1: J101.34, J104.11 (A1)
A2: J101.32, J104.10 (A2)
A3: J101.30, J104.9 (A3)
A4: J101.28, J104.8 (A4)
A5: J101.26, J104.7 (A5)
A6: J101.24, J104.6 (A6)
A7: J101.22, J104.5 (A7)
A8: J101.20, J104.27 (A8)
A9: J101.18, JP101.3 (B)
A9/CHIPID: J104.26 (A9), JP101.2 (C)
A10: J101.16, J104.23 (A10)
A11: J101.14, J104.25 (A11)
A12: J101.12, J104.4 (A12)
A13: J101.10, J104.28 (A13)
A14: J101.8, J104.29 (A14)
A15: J101.6, J104.3 (A15)
A16: J101.4, J104.2 (A16)
A17: J101.2, JP102.3 (B)
A17/CS2: J104.30 (A17), JP102.2 (C)
AD0: J102.1, J104.13 (D0)
AD1: J102.2, J104.14 (D1)
AD2: J102.3, J104.15 (D2)
AD3: J102.4, J104.17 (D3)
AD4: J102.5, J104.18 (D4)
AD5: J102.6, J104.19 (D5)
AD6: J102.7, J104.20 (D6)
AD7: J102.8, J104.21 (D7)
CHIPID: J103.1, JP101.1 (A)
CS2: J103.6, JP102.1 (A)
GND: J101.35, J102.9, J103.9, J104.16 (GND)
VCC: J101.31, J103.7, J104.32 (VCC)
~CE: J103.8, J104.22 (~CE)
~OE: J103.3, J104.24 (~OE)
~WE: J103.2, J104.31 (~PGM)

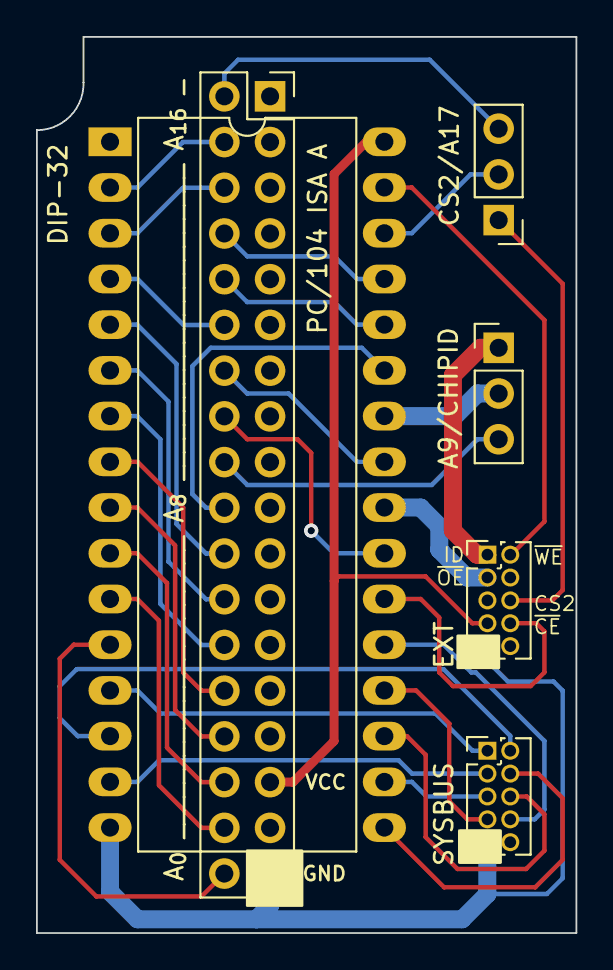
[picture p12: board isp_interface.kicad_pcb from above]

Board: 2 copper layers, 30.0 x 49.8 mm, 6 parts (0 on the bottom side), 35 nets.

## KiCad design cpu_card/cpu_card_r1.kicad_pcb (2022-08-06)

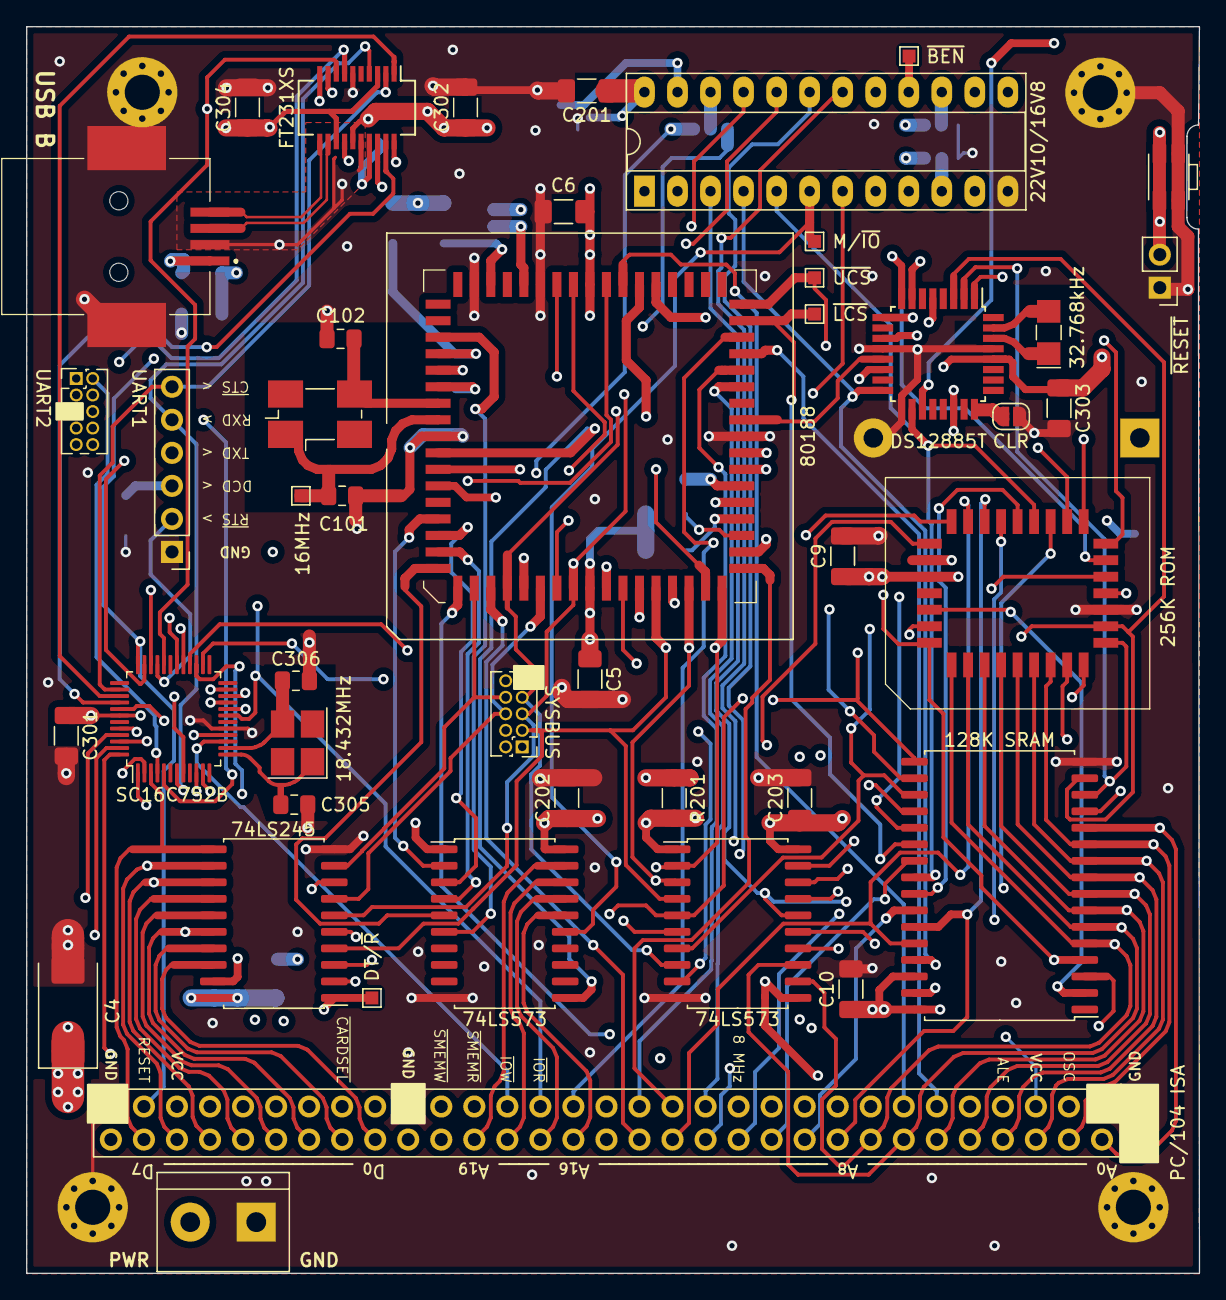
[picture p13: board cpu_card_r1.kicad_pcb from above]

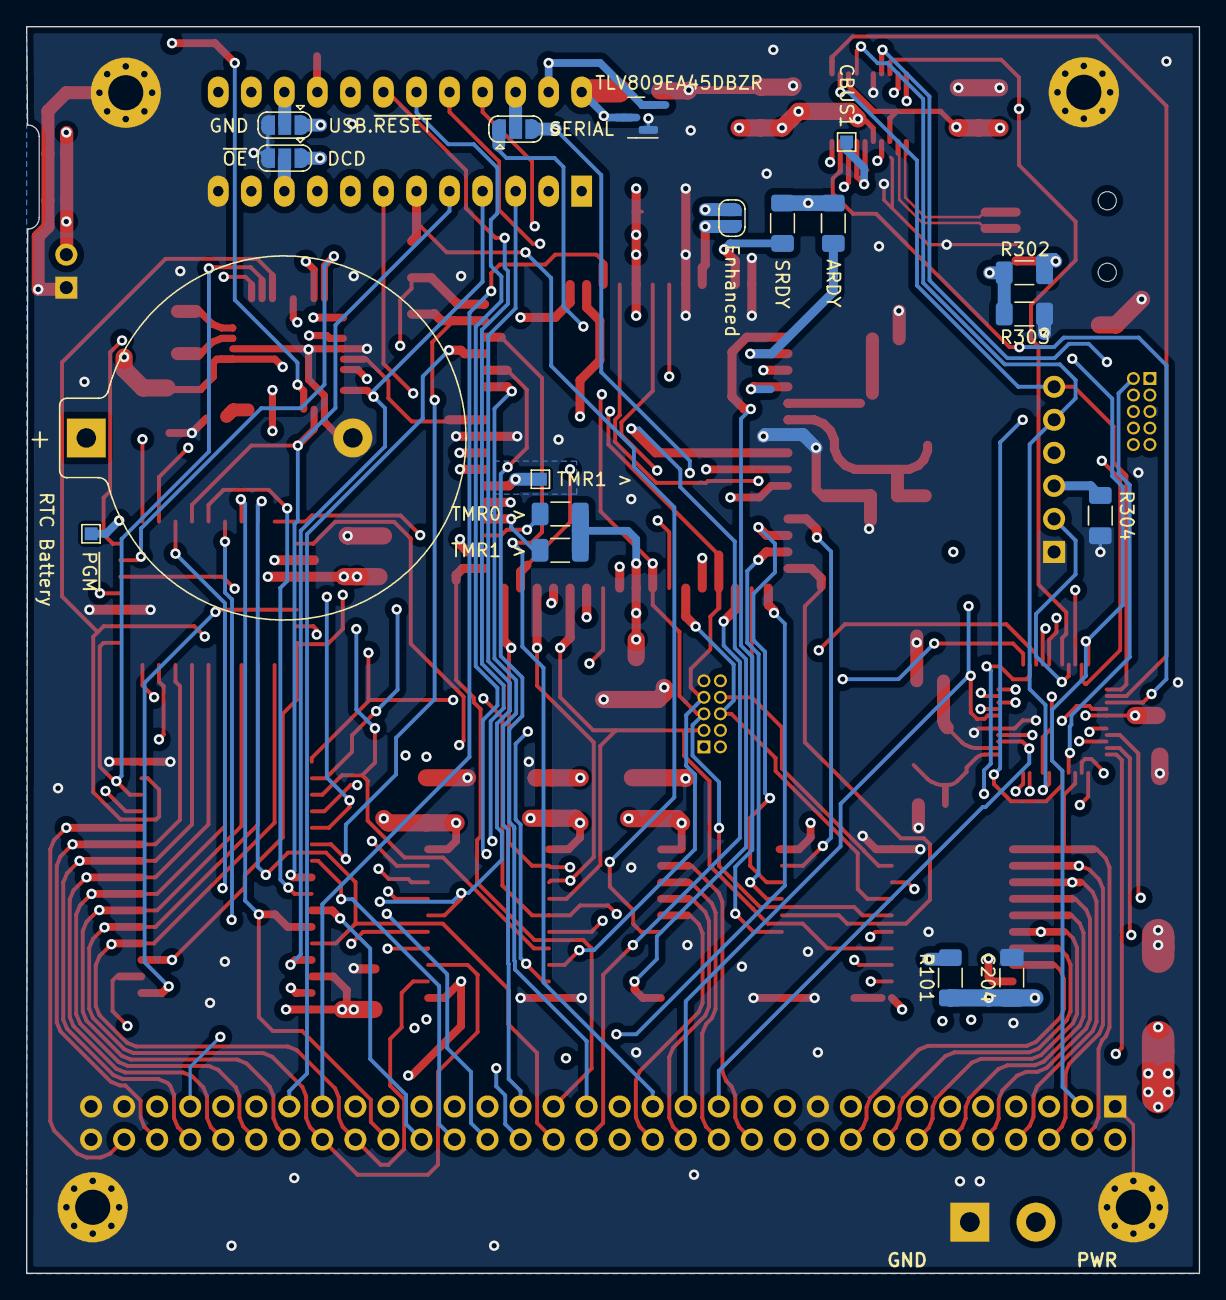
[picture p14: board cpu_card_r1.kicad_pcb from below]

Board: 4 copper layers, 90.2 x 95.8 mm, 67 parts (18 on the bottom side), 120 nets.

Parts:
BT301: RTC Battery; BatteryHolder_Keystone_106_1x20mm
C4: PPWR; CP_EIA-7343-31_Kemet-D
C5, C6, C9, C10, C201, C202, C203, C204, C301, C302, C303, C304: 100n/0.1u PWR; C_1206_3216Metric_Pad1.33x1.80mm_HandSolder
C101, C305: 22p XTAL; C_0805_2012Metric_Pad1.18x1.45mm_HandSolder
C102: 20p XTAL; C_0805_2012Metric_Pad1.18x1.45mm_HandSolder
C306: 33p XTAL; C_0805_2012Metric_Pad1.18x1.45mm_HandSolder
H1, H2, H3, H4: MountingHole_2.7mm_M2.5_Pad_Via
J1: 80188; PLCC-68_SMD-Socket
J2: PC/104 ISA; PinSocket_2x32_P2.54mm_Vertical
J4: 256K ROM; 69802132LF
J201: 22V10/16V8; DIP-24_W7.62mm_Socket_LongPads
J202: SYSBUS; PinHeader_2x05_P1.27mm_Vertical
J203: ~{RESET}; PinHeader_1x02_P2.54mm_Vertical
J301: UART1; PinHeader_1x06_P2.54mm_Vertical
J302: UART2; PinHeader_2x05_P1.27mm_Vertical
J303: USB B; AUSBBSMT
JP101: Enhanced; SolderJumper-2_P1.3mm_Open_RoundedPad1.0x1.5mm
JP201: ~{OE} DCD; SolderJumper-3_P1.3mm_Open_RoundedPad1.0x1.5mm
JP202: GND USB.~{RESET}; SolderJumper-3_P1.3mm_Open_RoundedPad1.0x1.5mm
JP203: SERIAL; SolderJumper-3_P1.3mm_Open_RoundedPad1.0x1.5mm
R1: TMR1 >; R_1206_3216Metric_Pad1.30x1.75mm_HandSolder
R2: ARDY; R_1206_3216Metric_Pad1.30x1.75mm_HandSolder
R3: SRDY; R_1206_3216Metric_Pad1.30x1.75mm_HandSolder
R4: TMR0 >; R_1206_3216Metric_Pad1.30x1.75mm_HandSolder
R101: PullUp; R_1206_3216Metric_Pad1.30x1.75mm_HandSolder
R201: Limit; R_1206_3216Metric_Pad1.30x1.75mm_HandSolder
R302: R4k7; R_1206_3216Metric_Pad1.30x1.75mm_HandSolder
R303: R10k; R_1206_3216Metric_Pad1.30x1.75mm_HandSolder
R304: PullDown; R_1206_3216Metric_Pad1.30x1.75mm_HandSolder
S1: PWR; TerminalBlock_bornier-2_P5.08mm
SW201: RESET; SW_SPST_EVQP7A
SW301: CLR; SolderJumper-2_P1.3mm_Open_RoundedPad1.0x1.5mm
TP101: XTAL; TestPoint_Pad_1.0x1.0mm
TP102: TMR1 >; TestPoint_Pad_1.0x1.0mm
TP103: ~{UCS}; TestPoint_Pad_1.0x1.0mm
TP104: ~{LCS}; TestPoint_Pad_1.0x1.0mm
TP105: ~{PGM}; TestPoint_Pad_1.0x1.0mm
TP201: M/~{IO}; TestPoint_Pad_1.0x1.0mm
TP202: DT/~{R}; TestPoint_Pad_1.0x1.0mm
TP203: ~{BEN}; TestPoint_Pad_1.0x1.0mm
TP302: CBUS1; TestPoint_Pad_1.0x1.0mm
U4: 128K SRAM; SSOP-32_11.305x20.495mm_P1.27mm
U201, U203: 74LS573; SOIC-20W_7.5x12.8mm_P1.27mm
U202: 74LS245; SOIC-20W_7.5x12.8mm_P1.27mm
U204: TLV809EA45DBZR; SOT-23
U301: SC16C752B; TQFP-48_7x7mm_P0.5mm
U302: FT231XS; SSOP-20_3.9x8.7mm_P0.635mm
U303: DS12885T; TQFP-32_7x7mm_P0.8mm
Y1: 16MHz; Crystal_SMD_0603-4Pin_6.0x3.5mm_HandSoldering
Y301: 18.432MHz; Crystal_SMD_3225-4Pin_3.2x2.5mm_HandSoldering
Y302: 32.768kHz; Crystal_SMD_EuroQuartz_EQ161-2Pin_3.2x1.5mm_HandSoldering

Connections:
16V8.GND: J201.15 (A0/O3), JP202.2 (C)
16V8.~OE: J201.10 (I8), JP201.2 (C)
/X1: C101.2, J1.59 (X1), TP101.1, Y1.1
/X2: C102.1, J1.58 (X2), Y1.3
A0: J2.62, J4.12 (A0), U4.12 (A0), U201.19 (Q0), U301.28 (A0)
A1: J2.60, J4.11 (A1), U4.11 (A1), U201.18 (Q1), U301.27 (A1)
A2: J2.58, J4.10 (A2), U4.10 (A2), U201.17 (Q2), U301.26 (A2)
A3: J2.56, J4.9 (A3), J201.3 (I1), U4.9 (A3), U201.16 (Q3)
A4: J2.54, J4.8 (A4), U4.8 (A4), U201.15 (Q4)
A5: J2.52, J4.7 (A5), U4.7 (A5), U201.14 (Q5)
A6: J2.50, J4.6 (A6), U4.6 (A6), U201.13 (Q6)
A7: J2.48, J4.5 (A7), U4.5 (A7), U201.12 (Q7)
A8: J1.16 (A8), J2.46, J4.27 (A8), U4.27 (A8)
A9: J1.14 (A9), J2.44, J4.26 (A9), U4.26 (A9)
A10: J1.12 (A10), J2.42, J4.23 (A10), U4.23 (A10)
A11: J1.10 (A11), J2.40, J4.25 (A11), U4.25 (A11)
A12: J1.7 (A12), J2.38, J4.4 (A12), U4.4 (A12)
A13: J1.5 (A13), J2.36, J4.28 (A13), U4.28 (A13)
A14: J1.3 (A14), J2.34, J4.29 (A14), U4.3 (A14)
A15: J1.1 (A15), J2.32, J4.3 (A15), U4.31 (A15)
A16: J2.30, J4.2 (A16), U4.2 (A16), U203.16 (Q3)
A17: J2.28, J4.30 (A17), U203.17 (Q2)
A18: J2.26, U203.18 (Q1)
A19: J2.24, U203.19 (Q0)
AD0: J1.17 (AD0), J4.13 (D0), J202.1, U4.13 (Q0), U201.2 (D0), U202.2 (A0), U303.1 (AD0)
AD1: J1.15 (AD1), J4.14 (D1), J202.2, U4.14 (Q1), U201.3 (D1), U202.3 (A1), U303.2 (AD1)
AD2: J1.13 (AD2), J4.15 (D2), J202.3, U4.15 (Q2), U201.4 (D2), U202.4 (A2), U303.3 (AD2)
AD3: J1.11 (AD3), J4.17 (D3), J202.4, U4.17 (Q3), U201.5 (D3), U202.5 (A3), U303.5 (AD3)
AD4: J1.8 (AD4), J4.18 (D4), J202.5, U4.18 (Q4), U201.6 (D4), U202.6 (A4), U303.7 (AD4)
AD5: J1.6 (AD5), J4.19 (D5), J202.6, U4.19 (Q5), U201.7 (D5), U202.7 (A5), U303.8 (AD5)
AD6: J1.4 (AD6), J4.20 (D6), J202.7, U4.20 (Q6), U201.8 (D6), U202.8 (A6), U303.9 (AD6)
AD7: J1.2 (AD7), J4.21 (D7), J202.8, U4.21 (Q7), U201.9 (D7), U202.9 (A7), U303.11 (AD7)
ALE: J1.61 (ALE/QS0), J2.55, U201.11 (Load), U203.11 (Load), U303.14 (AS)
BCLK: J1.56 (CLKOUT), J2.39
DB0: J2.18, U202.18 (B0), U301.44 (D0)
DB1: J2.16, U202.17 (B1), U301.45 (D1)
DB2: J2.14, U202.16 (B2), U301.46 (D2)
DB3: J2.12, U202.15 (B3), U301.47 (D3)
DB4: J2.10, U202.14 (B4), U301.48 (D4)
DB5: J2.8, U202.13 (B5), U301.1 (D5)
DB6: J2.6, U202.12 (B6), U301.2 (D6)
DB7: J2.4, U202.11 (B7), U301.3 (D7)
DCD: J301.3, JP201.1 (A), R304.2
DRQ0: J1.18 (DRQ0), J2.35
DRQ1: J1.19 (DRQ1), J2.11
DT/~R: J1.40 (DT/~R), TP202.1, U202.1 (A->B)
GND: BT301.2 (-), C4.2, C5.2, C6.2, C9.2, C10.2, C101.1, C102.2, C201.2, C202.2, C203.2, C204.2, C301.2, C302.2, C303.2, C304.2, C305.1, C306.2, H1.1, H2.1, H3.1, H4.1, J1.26 (VSS), J1.46 (NMI), J1.50 (HOLD), J1.60 (VSS), J2.1, J2.19, J2.61, J2.63, J2.64, J4.16 (GND), J201.12 (GND), J202.9, J203.1, J301.1, J302.5, J303.4 (GND), J303.5 (Shield), JP201.3 (B), JP202.3 (B), R303.2, R304.1, S1.1, SW201.2, SW301.1 (A), U4.16 (GND), U201.10 (GND), U202.10 (GND), U203.10 (GND), U204.1 (GND), U301.17 (GND), U302.6 (GND), U302.16 (GND), U303.12 (GND), U303.17 (GND), U303.29 (MOT)
INT0: J1.45 (INT0), U301.30 (INTA)
INT1: J1.44 (INT1/~SELECT), J2.7
INT2: J1.42 (INT2/~INTA0), U301.29 (INTB)
INT3: J1.41 (INT3/~INTA1/IRQ), J2.49
M/~IO: J201.6 (I4), TP201.1, U203.15 (Q4)
unnamed: C305.2, U301.13 (XTAL1), Y301.1
unnamed: C306.1, U301.14 (XTAL2), Y301.3
unnamed: J1.20 (TMR_IN_0), R4.2
unnamed: J1.21 (TMR_IN_1), R1.2
unnamed: J1.23 (TMR_OUT_1), TP102.1
unnamed: J1.47 (~TEST), JP101.2 (B)
unnamed: J1.49 (SRDY), R3.2
unnamed: J1.55 (ARDY), R2.2
unnamed: J4.31 (~PGM), TP105.1
unnamed: J201.22 (O1/A0), JP203.2 (C)
unnamed: SW301.2 (B), U303.24 (~RCLR)
unnamed: TP302.1, U302.17 (CBUS1)
unnamed: U303.30 (X1), Y302.1
unnamed: U303.31 (X2), Y302.2
RESET: J2.3, J201.17 (A2/O1), U301.36 (RESET)
RESOUT: J1.57 (RESET), J201.2 (I0), JP101.1 (A)
TMR_OUT_0: J1.22 (TMR_OUT_0), J2.59
UART1.IN: J301.4, U301.5 (RXA), U302.20 (TXD)
UART1.OUT: J301.5, U301.7 (TXA), U302.4 (RXD)
UART1.~CTS: J301.6, U301.38 (~CTSA), U302.2 (~RTS)
UART1.~DSR: U301.39 (~DSRA), U302.1 (~DTR)
UART1.~DTR: U301.34 (~DTRA), U302.7 (~DSR)
UART1.~RI: U301.41 (~RIA), U302.10 (CBUS2)
UART1.~RTS: J301.2, U301.33 (~RTSA), U302.9 (~CTS)
UART2.RX: J302.2, U301.4 (RXB)
UART2.TX: J302.3, U301.8 (TXB)
UART2.~CD: J302.1, U301.16 (~CDB)
UART2.~CTS: J302.8, U301.23 (~CTSB)
UART2.~DSR: J302.6, U301.20 (~DSRB)
UART2.~DTR: J302.4, U301.35 (~DTRB)
UART2.~RI: J302.9, U301.21 (~RIB)
UART2.~RTS: J302.7, U301.22 (~RTSB)
USB.D+: J303.3 (D+), U302.11 (USBDP)
USB.D-: J303.2 (D-), U302.12 (USBDM)
USB.VCC: C304.1, U302.3 (VCCIO), U302.13 (3V3OUT)
USB.~DCD: U301.32 (~OPA), U302.8 (~DCD)
USB.~PWREN: U301.40 (~CDA), U302.19 (CBUS3)
USB.~RESET: JP202.1 (A), U302.14 (~RESET)
VBAT: BT301.1 (+), U303.22 (VBAT)
VBUS: J303.1 (VBUS), R302.1
VBUS_SENSE: R302.2, R303.1, U302.18 (CBUS0)
VCC: C4.1, C5.1, C6.1, C9.1, C10.1, C201.1, C202.1, C203.1, C204.1, C301.1, C302.1, C303.1, J1.9 (VCC), J1.43 (VCC), J2.5, J2.57, J4.32 (VCC), J201.24 (VCC), R1.1, R2.1, R3.1, R4.1, R101.1, R201.1, S1.2, U4.30 (CS2), U4.32 (VCC), U201.20 (VCC), U202.20 (VCC), U203.20 (VCC), U204.3 (VCC), U301.42 (VCC), U302.15 (VCC), U303.28 (VCC)
XA16: J1.68 (A16/S3), U203.5 (D3)
XA17: J1.67 (A17/S4), U203.4 (D2)
XA18: J1.66 (A18/S5), U203.3 (D1)
XA19: J1.65 (A19/S6), U203.2 (D0)
~AL_OE: R201.2, U201.1 (OE), U203.1 (OE)
~BEN: J201.16 (A1/O2), TP203.1, U202.19 (CE)
~CARDSLCTD: J2.15, J201.8 (I6), R101.2
~CS_RTC: J1.27 (~PCS1), U303.13 (~CS)
~CS_S1: JP203.1 (A), U301.10 (~CSA)
~CS_S2: J201.14 (LR/O4), JP203.3 (B), U301.11 (~CSB)
~CS_S: J1.25 (~PCS0), J201.7 (I5)
~DEN: J1.39 (~DEN), J201.9 (I7)
~IOR: J2.27, J201.21 (O2/A1), U301.19 (~IOR)
~IOW: J2.25, J201.20 (O3/A2), U301.15 (~IOW)
~LCS: J1.33 (~LCS), TP104.1, U4.22 (~CS1)
~PCS3: J1.29 (~PCS3), J2.37
~PCS4: J1.30 (~PCS4), J2.33
~PCS5: J1.31 (~PCS5/A1), J2.51
~PCS6: J1.32 (~PCS6/A2), J2.29
~RD: J1.62 (~RD/~QSMD), J4.24 (~OE), J201.5 (I3), U4.24 (~OE), U303.18 (DS)
~RESET: J1.24 (~RES), J201.23 (O0/LR), J203.2, SW201.1, U204.2 (~RESET), U303.19 (~RESET)
~S2: J1.54 (~S2), U203.6 (D4)
~SMEMR: J2.23, J201.19 (O4/NC)
~SMEMW: J2.21, J201.18 (NC/O0)
~UCS: J1.34 (~UCS), J4.22 (~CE), TP103.1
~WR: J1.63 (~WR/QS1), J201.4 (I2), U4.29 (~WE), U303.16 (R/*W)

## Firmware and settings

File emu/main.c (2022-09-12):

/*
  Fake86: A portable, open-source 8086 PC emulator.
  Copyright (C)2010-2013 Mike Chambers

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
  You should have received a copy of the GNU General Public License
  along with this program; if not, write to the Free Software
  Foundation, Inc., 51 Franklin Street, Fifth Floor, Boston, MA  02110-1301, USA.
*/

/* main.c: functions to initialize the different components of Fake86,
   load ROM binaries, and kickstart the CPU emulator. */

#include "config.h"
#include "i8250.h"
#include "x186.h"
#include <stdint.h>
#include <stdio.h>
#include <stdlib.h>
#include <unistd.h>
#include <memory.h>

const uint8_t *build = BUILD_STRING;

extern uint8_t RAM[0x100000], readonly[0x100000];
extern uint8_t running, renderbenchmark;

extern void reset86();
extern void exec86 (uint32_t execloops);
extern uint8_t initscreen (uint8_t *ver);
extern void VideoThread();
extern doscrmodechange();
extern void handleinput();

#ifdef CPU_ADDR_MODE_CACHE
extern uint64_t cached_access_count, uncached_access_count;
#endif

extern uint8_t scrmodechange, doaudio;
extern uint64_t totalexec, totalframes;
uint64_t starttick, endtick, lasttick;

uint8_t *biosfile = NULL, verbose = 0, cgaonly = 0, useconsole = 0;
uint32_t speed = 0;


uint32_t loadbinary (uint32_t addr32, uint8_t *filename, uint8_t roflag) {
	FILE *binfile = NULL;
	uint32_t readsize;

	binfile = fopen (filename, "rb");
	if (binfile == NULL) {
			return (0);
		}

	fseek (binfile, 0, SEEK_END);
	readsize = ftell (binfile);
	fseek (binfile, 0, SEEK_SET);
	fread ( (void *) &RAM[addr32], 1, readsize, binfile);
	fclose (binfile);

	memset ( (void *) &readonly[addr32], roflag, readsize);
	return (readsize);
}

uint32_t loadrom (uint32_t addr32, uint8_t *filename, uint8_t failure_fatal) {
	uint32_t readsize;
	readsize = loadbinary (addr32, filename, 1);
	if (!readsize) {
			if (failure_fatal) printf("FATAL: ");
			else printf("WARNING: ");
			printf ("Unable to load %s\n", filename);
			return (0);
		}
	else {
			printf ("Loaded %s at 0x%05X (%lu KB)\n", filename, addr32, readsize >> 10);
			return (readsize);
		}
}

uint32_t loadbios (uint8_t *filename) {
	FILE *binfile = NULL;
	uint32_t readsize;

	binfile = fopen (filename, "rb");
	if (binfile == NULL) {
			return (0);
		}

	fseek (binfile, 0, SEEK_END);
	readsize = ftell (binfile);
	fseek (binfile, 0, SEEK_SET);
	fread ( (void *) &RAM[0x100000 - readsize], 1, readsize, binfile);
	fclose (binfile);

	memset ( (void *) &readonly[0x100000 - readsize], 1, readsize);
	return (readsize);
}

extern uint8_t insertdisk (uint8_t drivenum, char *filename);
extern void ejectdisk (uint8_t drivenum);
extern uint8_t bootdrive, ethif, net_enabled;
extern void doirq (uint8_t irqnum);
//extern void isa_ne2000_init(int baseport, uint8_t irq);
extern void parsecl (int argc, char *argv[]);
void timing();
void tickaudio();
void inittiming();
void initaudio();
void init8253();
void init8259();
void init8237();
extern void initcmos();
extern void initVideoPorts();
extern void killaudio();
extern void initsermouse (uint16_t baseport, uint8_t irq);
extern void *port_write_callback[0x10000];
extern void *port_read_callback[0x10000];
extern void *port_write_callback16[0x10000];
extern void *port_read_callback16[0x10000];
extern void initadlib (uint16_t baseport);
extern void initsoundsource();
extern void isa_ne2000_init (uint16_t baseport, uint8_t irq);
extern void initBlaster (uint16_t baseport, uint8_t irq);

#ifdef NETWORKING_ENABLED
extern void initpcap();
extern void dispatch();
#endif

void printbinary (uint8_t value) {
	int8_t curbit;

	for (curbit=7; curbit>=0; curbit--) {
			if ( (value >> curbit) & 1) printf ("1");
			else printf ("0");
		}
}

uint8_t usessource = 0;
void inithardware() {
	printf ("Initializing emulated hardware:\n");
	memset (port_write_callback, 0, sizeof (port_write_callback) );
	memset (port_read_callback, 0, sizeof (port_read_callback) );
	memset (port_write_callback16, 0, sizeof (port_write_callback16) );
	memset (port_read_callback16, 0, sizeof (port_read_callback16) );
	printf ("  - x186 platform: ");
	initx186();
	printf ("OK\n");
	printf ("  - Intel 8250 USART: ");
	init8250();
	printf ("OK\n");
	printf ("  - Intel 8253 timer: ");
	init8253();
	printf ("OK\n");
	printf ("  - Intel 8259 interrupt controller: ");
	init8259();
	printf ("OK\n");
	printf ("  - DS1285 real-time clock: ");
	initcmos();
	printf ("OK\n");
	inittiming();
}

uint8_t dohardreset = 0;
uint8_t audiobufferfilled();

void *EmuThread (void *dummy) {
	while (running) {
			if (!speed) exec86 (10000);
			else {
				exec86(speed / 100);
				timing();
				usleep(10000);
			}
			if (dohardreset) {
				reset86();
				dohardreset = 0;
			}
		}
}

void *runconsole (void *dummy);

int main (int argc, char *argv[]) {
	uint32_t biossize;

	printf ("%s (c)2010-2013 Mike Chambers\n", build);
	printf ("[A portable, open-source 8086 PC emulator]\n\n");

	parsecl (argc, argv);

	memset (readonly, 0, 0x100000);
	biossize = loadbios (biosfile);
	if (!biossize) return (-1);
/*
#ifdef DISK_CONTROLLER_ATA
	if (!loadrom (0xD0000UL, PATH_DATAFILES "ide_xt.bin", 1) ) return (-1);
#endif
	if (biossize <= 8192) {
		loadrom (0xF6000UL, PATH_DATAFILES "rombasic.bin", 0);
		if (!loadrom (0xC0000UL, PATH_DATAFILES "videorom.bin", 1) ) return (-1);
	}
*/
	printf ("\nInitializing CPU... ");
	running = 1;
	reset86();
	printf ("OK!\n");

	inithardware();

	EmuThread(NULL);
	//exec86 (10000);

	return (0);
}

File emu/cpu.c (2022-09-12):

/*
  Fake86: A portable, open-source 8086 PC emulator.
  Copyright (C)2010-2013 Mike Chambers

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
  You should have received a copy of the GNU General Public License
  along with this program; if not, write to the Free Software
  Foundation, Inc., 51 Franklin Street, Fifth Floor, Boston, MA  02110-1301, USA.
*/

/* cpu.c: functions to emulate the 8086/V20 CPU in software. the heart of Fake86. */

#include "config.h"
#ifndef CPU_INSTRUCTION_FLOW_CACHE

#include <stdint.h>
#include <stdio.h>
#include "cpu.h"
#include "i8259.h"
#include "i8253.h"
#include "modregrm.h"
#include "i8250.h"

extern struct i8253_s i8253;

extern struct structpic i8259;
uint64_t curtimer, lasttimer, timerfreq;

uint8_t byteregtable[8] = { regal, regcl, regdl, regbl, regah, regch, regdh, regbh };

static const uint8_t parity[0x100] = {
	1, 0, 0, 1, 0, 1, 1, 0, 0, 1, 1, 0, 1, 0, 0, 1, 0, 1, 1, 0, 1, 0, 0, 1, 1, 0, 0, 1, 0, 1, 1, 0,
	0, 1, 1, 0, 1, 0, 0, 1, 1, 0, 0, 1, 0, 1, 1, 0, 1, 0, 0, 1, 0, 1, 1, 0, 0, 1, 1, 0, 1, 0, 0, 1,
	0, 1, 1, 0, 1, 0, 0, 1, 1, 0, 0, 1, 0, 1, 1, 0, 1, 0, 0, 1, 0, 1, 1, 0, 0, 1, 1, 0, 1, 0, 0, 1,
	1, 0, 0, 1, 0, 1, 1, 0, 0, 1, 1, 0, 1, 0, 0, 1, 0, 1, 1, 0, 1, 0, 0, 1, 1, 0, 0, 1, 0, 1, 1, 0,
	0, 1, 1, 0, 1, 0, 0, 1, 1, 0, 0, 1, 0, 1, 1, 0, 1, 0, 0, 1, 0, 1, 1, 0, 0, 1, 1, 0, 1, 0, 0, 1,
	1, 0, 0, 1, 0, 1, 1, 0, 0, 1, 1, 0, 1, 0, 0, 1, 0, 1, 1, 0, 1, 0, 0, 1, 1, 0, 0, 1, 0, 1, 1, 0,
	1, 0, 0, 1, 0, 1, 1, 0, 0, 1, 1, 0, 1, 0, 0, 1, 0, 1, 1, 0, 1, 0, 0, 1, 1, 0, 0, 1, 0, 1, 1, 0,
	0, 1, 1, 0, 1, 0, 0, 1, 1, 0, 0, 1, 0, 1, 1, 0, 1, 0, 0, 1, 0, 1, 1, 0, 0, 1, 1, 0, 1, 0, 0, 1
};

uint8_t	RAM[0x100000], readonly[0x100000];
uint8_t	opcode, segoverride, reptype, bootdrive = 0, hdcount = 0, hltstate = 0;
uint16_t segregs[4], savecs, saveip, ip, useseg, oldsp;
uint8_t	tempcf, oldcf, cf, pf, af, zf, sf, tf, ifl, df, of, mode, reg, rm;
uint16_t oper1, oper2, res16, disp16, temp16, dummy, stacksize, frametemp;
uint8_t	oper1b, oper2b, res8, disp8, temp8, nestlev, addrbyte;
uint32_t temp1, temp2, temp3, temp4, temp5, temp32, tempaddr32, ea;
int32_t	result;
uint64_t totalexec;

extern uint16_t	VGA_SC[0x100], VGA_CRTC[0x100], VGA_ATTR[0x100], VGA_GC[0x100];
extern uint8_t updatedscreen;
union _bytewordregs_ regs;

uint8_t	portram[0x10000];
uint8_t	running = 0, debugmode, showcsip, verbose, mouseemu, didbootstrap = 0;
uint8_t	ethif;

extern uint8_t	vidmode;
extern uint8_t verbose;

extern void vidinterrupt();

extern uint8_t readVGA (uint32_t addr32);

void intcall86 (uint8_t intnum);

#define makeflagsword() \
	( \
	2 | (uint16_t) cf | ((uint16_t) pf << 2) | ((uint16_t) af << 4) | ((uint16_t) zf << 6) | ((uint16_t) sf << 7) | \
	((uint16_t) tf << 8) | ((uint16_t) ifl << 9) | ((uint16_t) df << 10) | ((uint16_t) of << 11) \
	)

#define decodeflagsword(x) { \
	temp16 = x; \
	cf = temp16 & 1; \
	pf = (temp16 >> 2) & 1; \
	af = (temp16 >> 4) & 1; \
	zf = (temp16 >> 6) & 1; \
	sf = (temp16 >> 7) & 1; \
	tf = (temp16 >> 8) & 1; \
	ifl = (temp16 >> 9) & 1; \
	df = (temp16 >> 10) & 1; \
	of = (temp16 >> 11) & 1; \
	}

extern void	writeVGA (uint32_t addr32, uint8_t value);
extern void	portout (uint16_t portnum, uint8_t value);
extern void	portout16 (uint16_t portnum, uint16_t value);
extern uint8_t	portin (uint16_t portnum);
extern uint16_t portin16 (uint16_t portnum);

void write86 (uint32_t addr32, uint8_t value) {
	tempaddr32 = addr32 & 0xFFFFF;
#ifdef CPU_ADDR_MODE_CACHE
	if (!readonly[tempaddr32]) addrcachevalid[tempaddr32] = 0;
#endif
	if (readonly[tempaddr32] || (tempaddr32 >= 0xC0000) ) {
			return;
		}

	if ( (tempaddr32 >= 0xA0000) && (tempaddr32 <= 0xBFFFF) ) {
			if ( (vidmode != 0x13) && (vidmode != 0x12) && (vidmode != 0xD) && (vidmode != 0x10) ) {
					RAM[tempaddr32] = value;
					updatedscreen = 1;
				}
			else if ( ( (VGA_SC[4] & 6) == 0) && (vidmode != 0xD) && (vidmode != 0x10) && (vidmode != 0x12) ) {
					RAM[tempaddr32] = value;
					updatedscreen = 1;
				}
			else {
					writeVGA (tempaddr32 - 0xA0000, value);
				}

			updatedscreen = 1;
		}
	else {
			RAM[tempaddr32] = value;
		}
}

void writew86 (uint32_t addr32, uint16_t value) {
	// printf("WR[%x] ", (int)addr32);
	write86 (addr32, (uint8_t) value);
	write86 (addr32 + 1, (uint8_t) (value >> 8) );
}

uint8_t read86 (uint32_t addr32) {
	addr32 &= 0xFFFFF;
	// printf("RD[%x] ", (int)addr32);
	if ( (addr32 >= 0xA0000) && (addr32 <= 0xBFFFF) ) {
			if ( (vidmode == 0xD) || (vidmode == 0xE) || (vidmode == 0x10) || (vidmode == 0x12) ) return (readVGA (addr32 - 0xA0000) );
			if ( (vidmode != 0x13) && (vidmode != 0x12) && (vidmode != 0xD) ) return (RAM[addr32]);
			if ( (VGA_SC[4] & 6) == 0)
				return (RAM[addr32]);
			else
				return (readVGA (addr32 - 0xA0000) );
		}

	if (!didbootstrap) {
			RAM[0x410] = 0x41; //ugly hack to make BIOS always believe we have an EGA/VGA card installed
			RAM[0x475] = hdcount; //the BIOS doesn't have any concept of hard drives, so here's another hack
		}

	return (RAM[addr32]);
}

uint16_t readw86 (uint32_t addr32) {
	return ( (uint16_t) read86 (addr32) | (uint16_t) (read86 (addr32 + 1) << 8) );
}

void flag_szp8 (uint8_t value) {
	if (!value) {
			zf = 1;
		}
	else {
			zf = 0;	/* set or clear zero flag */
		}

	if (value & 0x80) {
			sf = 1;
		}
	else {
			sf = 0;	/* set or clear sign flag */
		}

	pf = parity[value]; /* retrieve parity state from lookup table */
}

void flag_szp16 (uint16_t value) {
	if (!value) {
			zf = 1;
		}
	else {
			zf = 0;	/* set or clear zero flag */
		}

	if (value & 0x8000) {
			sf = 1;
		}
	else {
			sf = 0;	/* set or clear sign flag */
		}

	pf = parity[value & 255];	/* retrieve parity state from lookup table */
}

void flag_log8 (uint8_t value) {
	flag_szp8 (value);
	cf = 0;
	of = 0; /* bitwise logic ops always clear carry and overflow */
}

void flag_log16 (uint16_t value) {
	flag_szp16 (value);
	cf = 0;
	of = 0; /* bitwise logic ops always clear carry and overflow */
}

void flag_adc8 (uint8_t v1, uint8_t v2, uint8_t v3) {

	/* v1 = destination operand, v2 = source operand, v3 = carry flag */
	uint16_t	dst;

	dst = (uint16_t) v1 + (uint16_t) v2 + (uint16_t) v3;
	flag_szp8 ( (uint8_t) dst);
	if ( ( (dst ^ v1) & (dst ^ v2) & 0x80) == 0x80) {
			of = 1;
		}
	else {
			of = 0; /* set or clear overflow flag */
		}

	if (dst & 0xFF00) {
			cf = 1;
		}
	else {
			cf = 0; /* set or clear carry flag */
		}

	if ( ( (v1 ^ v2 ^ dst) & 0x10) == 0x10) {
			af = 1;
		}
	else {
			af = 0; /* set or clear auxilliary flag */
		}
}

void flag_adc16 (uint16_t v1, uint16_t v2, uint16_t v3) {

	uint32_t	dst;

	dst = (uint32_t) v1 + (uint32_t) v2 + (uint32_t) v3;
	flag_szp16 ( (uint16_t) dst);
	if ( ( ( (dst ^ v1) & (dst ^ v2) ) & 0x8000) == 0x8000) {
			of = 1;
		}
	else {
			of = 0;
		}

	if (dst & 0xFFFF0000) {
			cf = 1;
		}
	else {
			cf = 0;
		}

	if ( ( (v1 ^ v2 ^ dst) & 0x10) == 0x10) {
			af = 1;
		}
	else {
			af = 0;
		}
}
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

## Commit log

2022-05-11 kicad project
    [8088_cpu_card.kicad_pcb, 8088_cpu_card.kicad_sch, 8088_memory.kicad_pcb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]
2022-05-31 kinda working revision
    [61729-0010BLF.stp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]
2022-06-02 minimal viable board
    * PLD provides /IOW and TRG signals for reading all IO out
    * BIOS initialises the /UMCS and print debug
    [8088_cpu_card.kicad_pcb, 8088_cpu_card.kicad_sch]
2022-06-06 timer as a baud rate generator
2022-06-19 debug in progress: reset error flag, serial timer to 4800
2022-06-22 board fixes
    [8088_cpu_card.kicad_sch]
2022-06-29 debug part 1
    * pull-up for CARDSEL
    * memory test
    * test serial board on PCS3 and OSC/4 powered by timer1
2022-07-30 hw flow control for serial
    * GAL supports reading from serial
    * hw flow control initialised
2022-08-06 Board revision R2 and isp_interface
    * `isp_interface` to re-program the on-board flash
    * fixes in R1
    - `/AL_OE` to `RESET`
    - capacitor on `/RESET`
    [61729-0010BLF.stp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]
2022-08-08 bios library and overall cleanup
    [cpu_card.kicad_pcb, cpu_card.kicad_sch, glue.kicad_sch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]
2022-09-12 v0.4: cleanup and emulation
    * keyboard input in emulator
    * better RTC assembly and macro
    * linting
    * some IBM PC XT endpoints

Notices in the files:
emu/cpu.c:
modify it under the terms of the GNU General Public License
